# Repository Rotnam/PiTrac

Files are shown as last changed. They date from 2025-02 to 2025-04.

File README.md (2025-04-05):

**Introduction to PiTrac:**

- [Introduction](#introducing-pitrac)
  - [Project Page](#project-page)
- [PiTrac - Start Here](#getting-started)
- [PiTrac - Setup and Configuration](#setup-and-configuration)
- [PiTrac - Join the Discord](#join-the-discord)

## Introducing PiTrac
Introducing [PiTrac](https://hackaday.io/project/195042-pitrac-the-diy-golf-launch-monitor) \- the world’s first (free\!) open-source golf launch monitor (as far as we know). 



PiTrac uses low-cost Raspberry Pi(\*) computers and cameras to determine golf ball launch speed, angles and spin in three dimensions.  PiTrac interfaces with both GSPro and E6/TruGolf simulators, and its output is also accessible on a stand-alone web-based app.  \[We’ve reached out to 2k/TopGolf, but no response yet.\]

PiTrac uses off-the-shelf hardware, and includes a [parts list](https://github.com/jamespilgrim/PiTrac/blob/main/Documentation/PiTrac%20-%20DIY%20LM%20%20Parts%20List.md) with links to potential suppliers.  The only custom part is a small printed circuit board.  The fabrication instructions for that PCB are included in the open-source distribution and it can be manufactured for a few dollars.  The two Pi computers and cameras are the most expensive parts, and cost around $250 in total.

PiTrac is not a commercial product for sale–the full design is being released as open source on GitHub for folks to build themselves.  It’s not easy, but if you’re handy with a soldering iron, can figure out how to 3D print the parts, and are willing to burrow into the Linux operating system to compile and install software, you should be able to create your own PiTrac\!  

We are hoping that we can inspire a community of developers to help test and continue PiTrac’s development.  This is a really immature project right now.  The basic features usually work reliably, but the current release is a bit dodgy.  We’re looking for folks to try building their own PiTracs and help us improve the documentation and design to make it easier for other people to do the same.

## Project Page
Please visit our [project page](https://hackaday.io/project/195042-pitrac-the-diy-golf-launch-monitor) and also our YouTube channel [here](https://www.youtube.com/@PiTrac) for more details and videos.  The [GitHub repository](https://github.com/jamespilgrim/PiTrac) is in the works and already has the 3D printed part designs, the hardware design and initial software documentation.  If you’re interested in more of the details and some of PiTrac’s development history, please look through the [project logs](https://hackaday.io/project/195042-pitrac-the-diy-golf-launch-monitor#menu-logs).  

Finally, any help at our [support page](https://ko-fi.com/Pitrac) would be appreciated to continue this work and complete the release process.

(\*) Raspberry Pi is a trademark of Raspberry Pi Ltd.  The PiTrac project is not endorsed, sponsored by or associated with Raspberry Pi or Raspberry Pi products or services.

## [Getting Started](/Documentation/PiTrac%20–%20START%20HERE.md)
The process of building your own PiTrac DIY Launch Monitor is described here at a high level. There are several more-detailed instruction documents elsewhere in the PiTrac repository that are referred to below for various sub-assemblies and tasks like compiling the code and preparing the build environment.

## [Setup and Configuration](/Documentation/Raspberry%20Pi%20Setup%20and%20Configuration.md)
The instructions which are targeted toward getting setup on a step-by-step basis. These instructions start with a Raspberry Pi with nothing on it, and are meant to describe all the steps to get from that point to a working, compiled version of PiTrac.  PiTrac currently requires two Raspberry Pi’s, so the majority of these instructions will have to be repeated twice.  Because the ‘smaller’ Pi system that connects to Camera 2 is the only Pi that handles the Tomcat/Tomee web-based GUI for the system, there are a few more steps for that system.

## [Join the Discord](https://discord.gg/vGuyAAxXJH)
The PiTrac discord is where you can get help or show off your PiTrac build, discuss features and get to know other PiTrac builders. PiTrac is still a new project, so the Discord is a way to clear up any fuzzy parts of the initial ecosystem. Click the link above or copy this invite link in Discord: `https://discord.gg/9nEeVrPX`.

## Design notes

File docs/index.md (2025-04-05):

---
title: Home
layout: home
nav_order: 1
---

### PiTrac - The DIY Golf Launch Monitor

- As seen on [Hackaday](https://hackaday.io/project/195042-pitrac-the-diy-golf-launch-monitor)
- Also on [Reddit](https://www.reddit.com/r/Golfsimulator/comments/1hnwhx0/introducing_pitrac_the_open_source_launch_monitor/)

The PiTrac project is a fully-functional golf launch monitor that avoids the need for expensive high shutter-speed and high frame-rate cameras. We've developed techniques for high-speed, infrared, strobe-based image capture and processing using cameras such as the Pi Global Shutter camera (~US$50 retail) and Raspberry Pi single board computers.

PiTrac determines ball speed, launch angles, and spin in 3 axes. Its output is accessible on a stand-alone web app. Interfaces to popular golf-course simulators including GsPro and E6 are working. 2k/TopGolf never responded to our requests.

<p align="center">Introduction to PiTrac's Enclosure
&nbsp;
<iframe width="640" height="420" src="https://www.youtube.com/embed/1pX95VoKsS4?si=O_Mzlwz3F93mBZXC" frameborder="0" allowfullscreen></iframe>
</p>

----

[^1]: [It can take up to 10 minutes for changes to your site to publish after you push the changes to GitHub](https://docs.github.com/en/pages/setting-up-a-github-pages-site-with-jekyll/creating-a-github-pages-site-with-jekyll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).

[Just the Docs]: https://just-the-docs.github.io/just-the-docs/
[GitHub Pages]: https://docs.github.com/en/pages
[README]: https://github.com/just-the-docs/just-the-docs-template/blob/main/README.md
[Jekyll]: https://jekyllrb.com
[GitHub Pages / Actions workflow]: https://github.blog/changelog/2022-07-27-github-pages-custom-github-actions-workflows-beta/
[use this template]: https://github.com/just-the-docs/just-the-docs-template/generate

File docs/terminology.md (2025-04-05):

---
title: Terminology
layout: home
parent: Home
nav_order: 1.2
---

### Terminology 

<table>
  <tr>
    <th>Device</th>
    <th>Description</th>
    <th>Notes</th>
  </tr>
  <tr>
    <td>Flight Camera</td>
    <td>This is the modified camera that will be installed on the first floor of the enclosure. Bottom camera.</td>
    <td> 
    - This camera is attached to Core Pi.<br>
    - Previously known as camera 2. In scripts, may be referred as such.
    </td>
  </tr>
   <tr>
    <td>Tee Camera (As in, Tee off)</td>
    <td>This is an unmodified camera that will be installed on the top floor of the enclosure. Top camera</td>
    <td> 
    - This camera is attached to Tee Pi.<br>
    - Previously known as camera 1. In scripts, may be referred as such.
    </td>
  </tr>
     <tr>
    <td>Tee Pi </td>
    <td>This Raspberry Pi that is used for the shared directory--Samba Server. It is recommended that you use a faster Pi (e.g. Pi5) for this Pi. Installed on the top floor of the enclosure.</td>
    <td> 
    - Connected to the Tee Camera (The top floor Camera).<br>
    </td>
  </tr>
       <tr>
    <td>Flight Pi </td>
    <td>Flight Pi - used for messaging running ActiveMQ and Apache Tomee. Installed on the bottom floor of the enclosure.</td>
    <td> 
    - Connected to the Flight camera (the modified camera).<br>
    </td>
  </tr>
</table>

### PiTrac 
<a href="https://1drv.ms/i/c/35c1f51c7fbc7aba/IQSr4Eu550wjRoRfLHclEgkAARA1St3Qvlx-dvPuE9Aupqc?width=1024">
PiTrac
</a>

### Diagram
<a href="https://1drv.ms/i/c/35c1f51c7fbc7aba/IQRJJ03UsL98QbZK4ppRKmdsAQ_Gr50rl9IbFNyvEkk1Wyg?width=1030&height=894">
PiTrac Diagram
</a>

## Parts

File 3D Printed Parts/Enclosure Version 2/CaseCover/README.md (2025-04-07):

**Description:**

The Case Cover is the output protective (and aethetic) case that surrounds the inner component tower of the PiTrac version 2 enclosure.  The Case Cover consists of two parts - a Lower Half and an Upper Half.  This part separation is to allow the cover to printed on most standard-size 3D printers. The top part of the Case Cover also acts as a way of easily picking up the entire PiTrac unit.
A [FreeCAD 1.0](https://www.freecad.org/downloads.php) compatible parameterized model is included here along with .stl files.

**Printing Notes:**

PLA works well for this, but PETG probably would as well. 

Recommended print settings: 2 perimeter layers, 15% infill, grid or rectilinear infill patterns, custom painted-on supports (see the Prusa Slicer .3mf file for where the supports are needed). Both upper and lower halves require glue-stick glue on the printer bed and we recommend a 7mm brim assist because of the very small print base surface.
You'll want to paint on supports and support-exclusions so that the only places with support on the upper half of the case are the three rectangular holes that provide access to the Compute Board.

**Assembly Notes:**

See the [main assembly instructions](https://github.com/jamespilgrim/PiTrac/blob/main/Documentation/PiTrac%20Version%202%20Assembly.md).
Ultimately, the two parts will be glued together with something like thick, slower-drying super-glue such as Starbond Gap Filler Thick High Performance Super Glue.

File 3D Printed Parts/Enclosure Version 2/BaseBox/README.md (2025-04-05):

**Description:**

The Basebox is the base of the PiTrac version 2 enclosure.  The Basebox consists of three parts - a Main Body, an End-Cap that fits into the body, and a Light Shield that fits into the other two parts.  The Basebox houses the Meanwell power supply unit and secures the tower that holds all of the electronics, cameras, and other parts. 
A [FreeCAD 1.0](https://www.freecad.org/downloads.php) compatible parameterized model is included here along with .stl files.

**Printing Notes:**

PLA works well for this, but PETG probably would as well. The main body is printed standing on its closed end, which makes for a pretty high print.  You may need to make sure your printer won't have problems near the top of the print.

Recommended print settings: 2 perimeter layers (3 for a little more strength), 15% infill, grid or rectilinear infill patterns, custom painted-on supports (see the Prusa Slicer .3mf file for where the supports are needed). The main body requires glue-stick glue on the printer bed and we recommend a 7mm brim assist because of the height and relatively small print base.  
The end-cap is a pretty easy print, and should not need glue or a brim.

The Light Shield Body prints pretty well with any settings, but we use 2 perimeter layers, 15% infill, grid infill and no supports, brims, or glue.

Note that a beginning of a sketch for an x-shaped leveling support base has been started in the model, but is not finished and not yet printable.

**Assembly Notes:**

See the [main assembly instructions](https://github.com/jamespilgrim/PiTrac/blob/main/Documentation/PiTrac%20Version%202%20Assembly.md).

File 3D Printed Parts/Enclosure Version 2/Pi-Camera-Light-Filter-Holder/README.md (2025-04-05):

**Description:**

This holder secures a 1”x1” filter on the front of a standard 6mm 3MP Wide Angle Lens for Raspberry Pi Cameras. The filter slips into the pocket (held by friction), and then the holder attaches to the front of the lens via a simple friction mount. A [FreeCAD 1.0](https://www.freecad.org/downloads.php) compatible parameterized model is included here along with .stl files.

The [DIY golf launch monitor project](https://hackaday.io/project/195042-diy-golf-launch-monitor) is using this filter to restrict the light entering a Pi Global Shutter Camera sensor to just infrared (IR) light. The filter for the project is a [1" x 1", Optical Cast Plastic IR Longpass Filter](https://www.edmundoptics.com/p/1quot-x-1quot-optical-cast-plastic-ir-longpass-filter/5421/) (1.5mm nominal thickness), but the model is parameterized, so the holder can easily be modified to fit other thicknesses (or sizes) by modifying the parameter in the “Master Document” spreadsheet named “'PiFilterHolderFilterThickness”.

Consider supporting this work and the DIY LM project here: <https://ko-fi.com/PiTrac> Please and Thank You!

**Printing Notes:**

PETG works better for flexibility of the holder, but PLA also works. The holder is modeled in two pieces because we struggled with the mess added by supports in a single filter. But, if folks can improve on this, that would be great! Maybe print the whole thing at 45 degrees?

Recommended print settings: 2 perimeter layers, 20% infill, gyroid infill patterns, no supports. Does not required glue-stick or brim assists.

**Assembly Notes:**

Use just a few small drops of cyanoacrylate (super) glue to attach the outer filter holder to the part of the holder that slips over the lens. Otherwise, the glue may restrict the passage into which the filter is placed. Use the little lip around the holder to position the two pieces while gluing. Avoid gluing top portion of filter window where the little retainer bumps are. This allows the retainer to flex a bit when the filter moves past it. After setting/drying, a 1” filter should just slip in and click securely into place.

To remove the filter, if necessary, use a small screw-driver to push the filter out using the little window on the bottom of the holder.

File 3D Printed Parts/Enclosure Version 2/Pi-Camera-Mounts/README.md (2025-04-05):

**Description:**

A camera mount that accommodates the Pi GS (Global Shutter) and HQ cameras with an attached 6mm 3MP Wide Angle Lens for Raspberry Pi Cameras. The mount can tilt up/down and swivel around a bolt that attaches the base of the mount to a flat surface. A [FreeCAD 1.0](https://www.freecad.org/downloads.php) compatible parameterized model is included here along with .stl files.

The [DIY golf launch monitor project](https://hackaday.io/project/195042-diy-golf-launch-monitor) is using these mounts for two Pi Global Shutter Cameras that capture the images for the monitor. Several variations can be printed—see the annotated printed-part image. One variation is relatively low for use with a camera whose up/down tilt is minimal. Another variation is taller, allowing the camera to be tiled down by at least 30 degrees. The model is parameterized, so the mount can easily be modified to fit other needs by modifying the parameters in the “Master Document” spreadsheet, such as the “GSCam2GimbalHoleHeight” parameter. Ensure that there will be sufficient clearance between the CSI ribbon cable on the bottom of the camera and the gimbal base of the mount.

Please consider supporting this work and the DIY LM project here: <https://ko-fi.com/PiTrac>

**Printing Notes:**

PLA or PETG works well with this mount.

Recommended print settings: 4 perimeter layers (less if the bolts are not expected to be tightened very much), 15% infill, grid infill patterns, no supports. For some printers, supports to help with the curved surfaces that rotate around the horizontal axes. See .3mf file. Does not required glue-stick or brim assists.

**Parts Needed for Assembly:**

| **Quantity** | **Hardware** | **Purpose** |
| --- | --- | --- |
| 4 each | 2.5M x 16mm<br><br>2.5 Hex Nuts | Pi Camera Attachment Bolts (camera to back plate) |
| --- | --- | --- |
| 2 each | M4 x 12mm <br><br>M4 Hex Nuts | Pi Cam Gimbal Attachment Hinge |
| --- | --- | --- |
| 1 each | M5 x 12<br><br>M5 Hex Nut | Pi Cam (Pan) Swivel Mount (on bottom of mount) |
| --- | --- | --- |

**Note:** For the screws, stainless steel seems to be stronger than black carbon steel, though both can work. Especially in the stiffer PLA material, stainless is preferable because black carbon can break if torqued too much. For parts supply examples see [HanTof 525 Pcs 304 Stainless Steel M2 M3 M4 Phillips Pan Head Self Tapping Wood screws Assortment Kit](https://www.googleadservices.com/pagead/aclk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)., mxuteuk M2.5 Screw Assortment Set,M2.5 x 4/6/8/10/12/16/20/25mm Hex Socket Head Cap Screws Bolts Nuts Kit,400PCS 304 Stainless Steel Assorted Screws with Hex Wrench G035-M2.5, and [Besitu 1760pcs M2 M3 M4 M5 Metric Screw Assortment, Grade 12.9 Alloy Steel Hex Socket Head Cap Metric Bolts and Nuts Kit, Black Zinc Plated and Anti Rust Metric Screw Set with 4 pcs Hex Wrenches](https://www.amazon.com/dp/B0C38YFL3D?ref=ppx_yo2ov_dt_b_fed_asin_title)

**Assembly Notes:**

Start by placing the nuts in their positions. It’s easier to place each of the three nuts into its respective indent, and then temporarily place a strip of tape (e.g., scotch) over the nut to keep it in place while assembling the mount. Next, mount the camera to the backplate using 4 2.5M bolts and nuts. Then mount the backplate to the gimbal base using 2 M4 bolts. Finally, secure the entire mount to whatever base will hold it by using an M5 bolt.

The mount’s tilt and pan angles will generally stay put once the nuts are tightened, simply based on the friction between the parts. If the angles cannot be finely tuned, sanding the parts helps.

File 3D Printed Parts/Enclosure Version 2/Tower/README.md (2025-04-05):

**Description:**

The Tower component is the backbone of PiTrac.  Most of the components (cameras, strobe, and Compute Board PCBA) are mounted on the front of the Tower. The Tower consists of two parts - a Frontplate and a Backplate.  This part separation is to allow the Tower to printed with a minimum of supports.  The top part of the Case Cover (and particularly the Shank Shield risers that the shield scews into) can also act as a way of easily picking up the entire PiTrac unit.
The Tower does not include the Shank Shield, which is made from a piece of 3/16" or 1/4" polycarbonite (recommended for durability) or plexiglas.
The Frontplate and Backplates parts are each further split into two halves to allow printing.  The height would otherwise be too tall for most printers.  
As discussed in the Assembly Notes, these resulting four parts are glued and screwed together to make up the tower.
A [FreeCAD 1.0](https://www.freecad.org/downloads.php) compatible parameterized model is included here along with .stl files.

**Printing Notes:**

If you are slicing the parts yourself, you will need to manually split each of the Frontplate and Backplate.  See the [FIGURE- 'Frontplate Split Example - Prusa.png'] for how to do this on the Prusa Slicer.  Other Slicers have a similar ability to slice the parts.  
In order to result in a strong combined tower part with strong lap-joints, we suggest splitting the Frontplate 104mm up from the bottom and the Backplate up 145mm).  See the two Datum planes in the FreeCad 3D model called 'Suggested Frontplate Split DatumPlane' and 'Suggested Backplate Split DatumPlane' for confimation of these cut-planes.

PLA works well for this, but PETG probably would as well. 

Recommended print settings: 2 perimeter layers, 15% infill, grid or rectilinear infill patterns.  No supports or brims should be necessary.

**Assembly Notes:**

See the [main assembly instructions](https://github.com/jamespilgrim/PiTrac/blob/main/Documentation/PiTrac%20Version%202%20Assembly.md).
Ultimately, the four parts will be glued together with something like thick, slower-drying super-glue such as Starbond Gap Filler Thick High Performance Super Glue and then screwed together with 
12 M2 x 6 self-tapping screws.

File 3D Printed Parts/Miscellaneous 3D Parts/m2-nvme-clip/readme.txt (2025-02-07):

Print with 0.08mm (extra fine) or 0.12, (fine) layer height, support on build plate only - tree(auto) - style: tree slim

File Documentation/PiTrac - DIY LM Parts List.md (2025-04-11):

**PiTrac \- DIY LM  Parts Lists**

**Computing Hardware:**

| Quantity | Hardware | Purpose |
| :---- | :---- | :---- |
| 1 | [Raspberry Pi 5](https://www.raspberrypi.com/products/raspberry-pi-5/) and power supply, 4 GB minimum, 8 FB recommended. | Getting a bundled kit with the Pi and power supply and some other things can be economical if you don’t have any Pi-related stuff yet. |
| 1 | [Raspberry Pi 4 Model B](https://www.raspberrypi.com/products/raspberry-pi-4-model-b/) and power supply, 4 GB minimum.  It may also make sense for a little more money just to get a second Pi 5\. |  |
| 1 | [Pimoroni NVMe Base for Raspberry Pi 5 \- PIM699](https://www.adafruit.com/product/5845) ((optional, but recommended for speed and longevity). [This board](https://www.amazon.com/gp/product/B0CQ4D2C9S/ref=ppx_yo_dt_b_search_asin_title?ie=UTF8&psc=1) works well, too. | For the Pi 5, this allows use of an NVMe memory drive instead of an MicroSD card. |
| 1 | An [NVMe solid state (SSD) memory drive](https://www.amazon.com/gp/product/B0BGFRZDTB/ref=ppx_yo_dt_b_search_asin_title?ie=UTF8&psc=1) (optional, but recommended for speed and longevity) | Typically with an M.2 M key edge connector, in the 2230 and 2242 form factors.  Should probably get at least 256 GB capacity. |
| 2 | Micro SD cards (to bootstrap the Pi’s). | We recommend 64GB size |
| 1 | An Active Cooler fan for the Pi 5 (optional) | The Pi 5 can get pretty hot if you’re doing a lot of big compiles on it.  If so, having a cooler seems like decent insurance. |

**Hardware \- Bolts and Nuts:[^1]**

| Quantity | Hardware | Purpose |
| :---- | :---- | :---- |
| 4 | M4 x 12 screws | LED Power supply hold-downs |
|  |  |  |
| 4 | 2.5M x 12mm bolt | Pi 1 Board Bolt-down |
| 4 | 2.5 Hex Nuts | Pi 1 Board Bolt-down |
| 3 | 2.5M x 10mm bolt | Pi 2 Board Bolt-down |
| 1 | 2.5M x 12mm bolt (odd one\!) | Pi 2 Board Bolt-down |
|  |  |  |
| 2 x 4 | 2.5M x 16mm 2.5 Hex Nuts | Pi Camera Attachment Bolts (to back plate) |
| 3 x 2 3 x 2 | M4 x 12mm  M4 Hex Nuts  | Pi Cam Gimbal Attachment Hinge (2 cameras and strobe gimbal) |
| 2 x 1 2 x 1 | M5 x 12 M5 Hex Nut | Pi Cam (Pan) Swivel Mount (on bottom of mount) |
|  |  |  |
| 3 x 2 | M3 | Horizontal Center-Side Body Attachment |
| 4 | 2.5 x 10 or 12 | Connector Board Bolt-down |
| 3 x 6 \= 18 | M3 x 10mm | Floor hold-down screws |
|  |  |  |
| 2 x 4 | 2.5M x 12mm bolt | Connector Board Mounting Bolts |
| 2 x 4 | 2.5 Hex Nuts | Connector Board Mounting Bolts |
| 8 | M3 x 10mm | LED and LED Lens Hold-down screws |
|  |  |  |
| 2 2 | M3 x 12mm M3 Nuts | Half-Join bolts and nuts for ceiling level walls |
| 2 2 | M3 x 16mm M3 Nuts | Half-Join bolts and nuts for base and middle level walls |
| 5 x 4 | M3 x 10mm self-tapping screws | These screws secure the five “floor” components to their respective “wall” components and/or other floor components |

**Camera and Lighting Hardware:**

| 2  | [Raspberry Pi Global Shutter Camera – CS Lens Mount](https://www.adafruit.com/product/5702) | The cameras currently used by the LM.  They do not come with lenses (see below) |
| :---- | :---- | :---- |
| 1 | [Raspberry Pi 5 FPC Camera Cable \- 22-pin 0.5mm to 15-pin 1mm \- 300mm long](https://www.adafruit.com/product/5819) | The current Pi Cameras have a CSI cable that needs a conversion to fit into the smaller CSI ports on the Pi 5\.  The 200mm should probably work as well. |
|  | [200 mm Flex Cable for Pi 4](https://www.adafruit.com/product/2087) | This likely comes with most Pi Cameras, so may not be necessary |
| 2 | [6mm 3MP Wide Angle Lens for Raspberry Pi HQ Camera \- 3MP](https://www.adafruit.com/product/4563) | Wide angle lens for the Pi GS cameras (which come without a lens) |
| 1 | [1" x 1", Optical Cast Plastic IR Longpass Filter](https://www.edmundoptics.com/p/1quot-x-1quot-optical-cast-plastic-ir-longpass-filter/5421/) (1.5mm nominal thickness) | Blocks visible light below 850nm from entering the Camera 2 sensor |
|  |  |  |
| 1 | [60 / 120 Degree LED Lens Optical Glass 44mm \+ Reflector Collimator \+ Fixed Bracket for 20W 30W 50W 100W COB High Power Chip (60Degree 100W len kit)](https://www.amazon.com/dp/B09XK7QTV5?ref=ppx_yo2ov_dt_b_fed_asin_title)  | The lens helps focus the infrared IR light. |
| 1 | [High Power LED Chip IR 730nm (you want the 850nm) 850nm 940nm 3W 5W 10W 20W 30W 50W 100W COB Integrated Matrix Light Beads for Night Vision Camera (Select the 850NM, 100W 1Pieces)](https://www.amazon.com/dp/B09DPJYRQN?ref=ppx_yo2ov_dt_b_product_details&th=1)  | The 730nm IR Led used for strobe light.  NOTE \- this device can get very hot if left constantly on for even a few seconds.  PiTrac just uses it in short pulses. |
| 1 | [Aclorol USB COB LED Strip Lights for TV 5V USB Powered LED Tape Lights Daylight White 6.56FT 320Leds/M 6000K COB Flexible Light Strip TV Led Backlight for Bedroom Under Cabinet Kitchen DIY](https://www.amazon.com/Aclorol-Powered-Daylight-Flexible-Backlight/dp/B0D1FYV3LM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) | LED strip for lighting the teed-up ball- long enough to double it for more light. 
NOTE - The Strip should produce NO infrared light, or else it will interfere with the IR strobing that the system uses.
|

**Power-Related Parts:**

| 1  | LED Driver, 12-26V, Output Current DC 3600mA, such as: https://www.aliexpress.us/item/2251832563139779.html NOTE - Also need a power-plug for some of these drivers that just come with power wires.  For the US, see, e.g., [this](https://www.amazon.com/sspa/click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)| Driver for LED strobe array. Because of the short pulses that are used in the LM, a much smaller (and cheaper) driver may also work, possibly even a non-constant-current driver. |
| :---- | :---- | :---- |
| 1 | A 5V USB-B power supply with a male micro USB connector  | This is currently necessary to run the Connectro Board.  The supply is used as an isolated, independent (downstream of a transformer) power plane to try to keep the Pi’s and the Pi Camera safe. |
|  |  |  |

**Connector Board Parts:**

| Item | Qty | Reference(s) | Value | LibPart | Footprint / Details |  |
| :---- | :---- | :---- | :---- | :---- | :---- | ----- |
| 1 | 1 | J3 | \~ | [USB B Micro Female Pinboard](https://www.amazon.com/Pinboard-MELIFE-Interface-Adapter-Breakout/dp/B07W6T97HZ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) | The included Pin headers can be used for the parts below |  |
| 2 | 2 | R1, R4 | 330 ohm R | Resistor A decent assortment kit is [here](https://www.amazon.com/gp/product/B003UC4FSS/ref=ppx_yo_dt_b_search_asin_title?ie=UTF8&psc=1) | Resistor\_THT:R\_Axial\_DIN0207\_L6.3mm\_D2.5mm\_P10.16mm\_Horizontal |  |
| 3 | 2 | R2, R3 | 270 ohm R | Resistor | Resistor\_THT:R\_Axial\_DIN0207\_L6.3mm\_D2.5mm\_P10.16mm\_Horizontal |  |
| 5 | 1 | Sys1\_Conn1 | \~ | 4 Pin Header | Connector\_PinHeader\_2.54mm:PinHeader\_1x04\_P2.54mm\_Vertical |  |
| 6 | 1 | Sys2\_Conn1 | \~ | 3 Pin Header | Connector\_PinHeader\_2.54mm:PinHeader\_1x03\_P2.54mm\_Vertical |  |
| 7 | 2 | U2, U3 | H11L1 | [Isolator:H11L1](https://www.amazon.com/dp/B09KM2BJCF?ref_=pe_386300_442618370_TE_sc_as_ri_0) | Package\_DIP:DIP-6\_W7.62mm |  |
| 8 | 1 | U4 | 74HC04 | 74xx:74HC04 | Package\_DIP:DIP-14\_W7.62mm\_Socket |  |
| 9 | 1 | U5 | \~ | [Dual\_Mos\_Driver\_Module](https://www.amazon.com/Anmbest-High-Power-Adjustment-Electronic-Brightness/dp/B07NWD8W26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) | Verdant\_Custom\_Footprint\_Library:PCB Dual MOS Driver Module |  |
|  | 1 | 2.5M Bolt 2.5M Nut |  |  | These help mechanically tie down the USB-B power connector to the board |  |
|  |  | \<Optional\> |  |  |  |  |
|  | 2 | 6 \- pin DIP socket |  | A decent assortment kit is [here](https://www.amazon.com/dp/B01GOLSUAU?ref=ppx_yo2ov_dt_b_fed_asin_title) | The opto-isolators and the hex inverter chip are probably the most likely to be blown up or injured by solder over-temps.  So best to put them in sockets |  |
|  | 1 | 14 \- pin DIP socket |  | A decent assortment kit is [here](https://www.amazon.com/dp/B01GOLSUAU?ref=ppx_yo2ov_dt_b_fed_asin_title) |  |  |

**Miscellaneous Parts/Supplies:**

| Quantity | Hardware | Purpose / Notes |
| :---- | :---- | :---- |
| 2 |  [Ideal Industries 30-102 Power Plug](https://www.amazon.com/Ideal-Industries-30-102-Power-72427/dp/B01LYF1WV9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). | Enables easy connect/disconnects |
| N/A | 3 and 4-pin ribbon cables For example, [here](https://www.amazon.com/Kidisoii-Dupont-Connector-Pre-Crimped-5P-10CM/dp/B0CCV1HVM9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). | These are used for the wiring harness connects between the various GPIO pins and the Connector Board |
| 1 | 15.5cm x 24cm plexiglass anti-ball-strike protective window | Protects the cameras and strobe **NOTE:**  Ensure the plexi is not IR-blocking\!  Most hardware stores can cut plexi in this size for a few US$ |
| 1 | Power Strip | A relatively short power strip that is compact enough to fit into the enclosure. 10” or less, and with some type of power filtering to protect the rest of the components |

[^1]:  Stainless Steel seems to be stronger than black carbon steel, though both can work.  Especially in the stiffer PLA material, stainless is preferable because black carbon can break if torqued too much..  For parts supply example see [HanTof 525 Pcs 304 Stainless Steel M2 M3 M4 Phillips Pan Head Self Tapping Wood screws Assortment Kit](https://www.googleadservices.com/pagead/aclk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).,

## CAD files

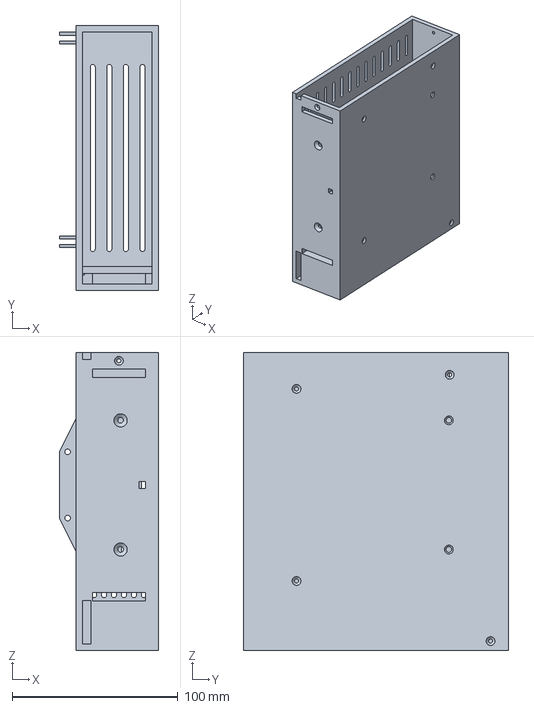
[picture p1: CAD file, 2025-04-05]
3D Printed Parts/Enclosure Version 2/BaseBox/BaseBox- Main Body.3mf
60.0 x 160.0 x 180.0 mm

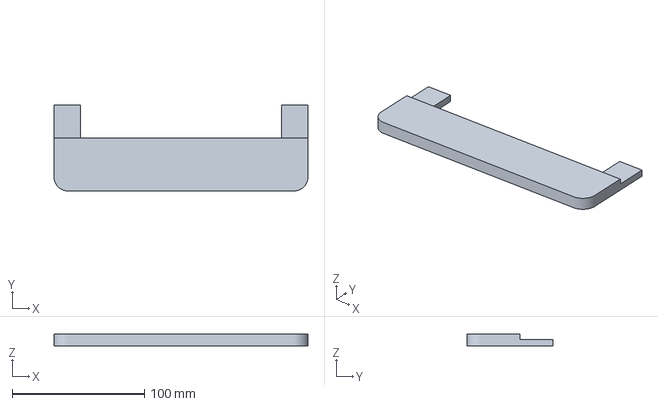
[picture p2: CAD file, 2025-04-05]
3D Printed Parts/Enclosure Version 2/BaseBox/BaseBox- Light Shield Body.3mf
192.0 x 65.0 x 9.00 mm

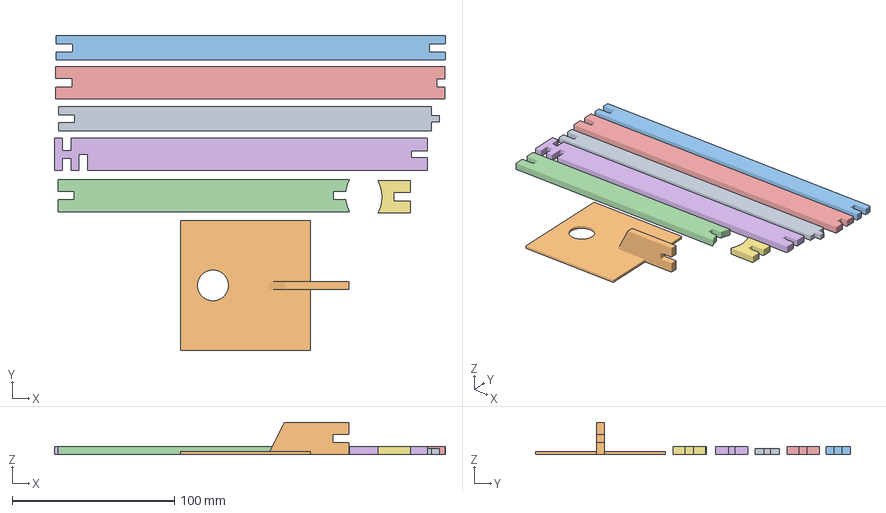
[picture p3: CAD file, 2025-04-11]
3D Printed Parts/Enclosure Version 2/Calibration Rig/Calibration Rig.3mf
241.1 x 194.0 x 20.0 mm
Calibration Rig.stl_1
Calibration Rig.stl_2
Calibration Rig.stl_3
Calibration Rig.stl_4
Calibration Rig.stl_5
Calibration Rig.stl_6
Calibration Rig.stl_8

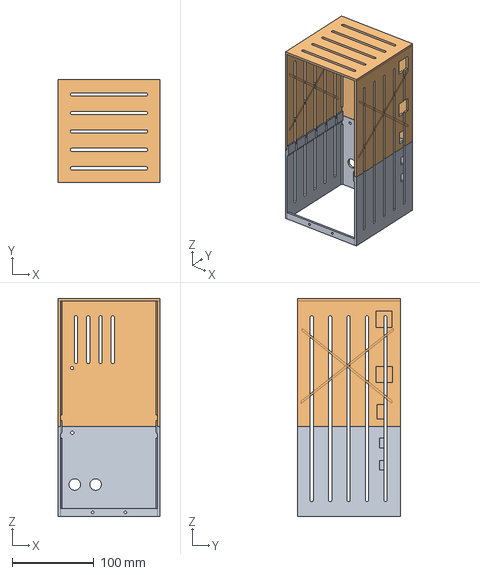
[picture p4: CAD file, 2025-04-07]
3D Printed Parts/Enclosure Version 2/CaseCover/CaseCover.FCStd
124.6 x 126.0 x 266.1 mm
Lower Case Cover Body
Upper Case Cover Body

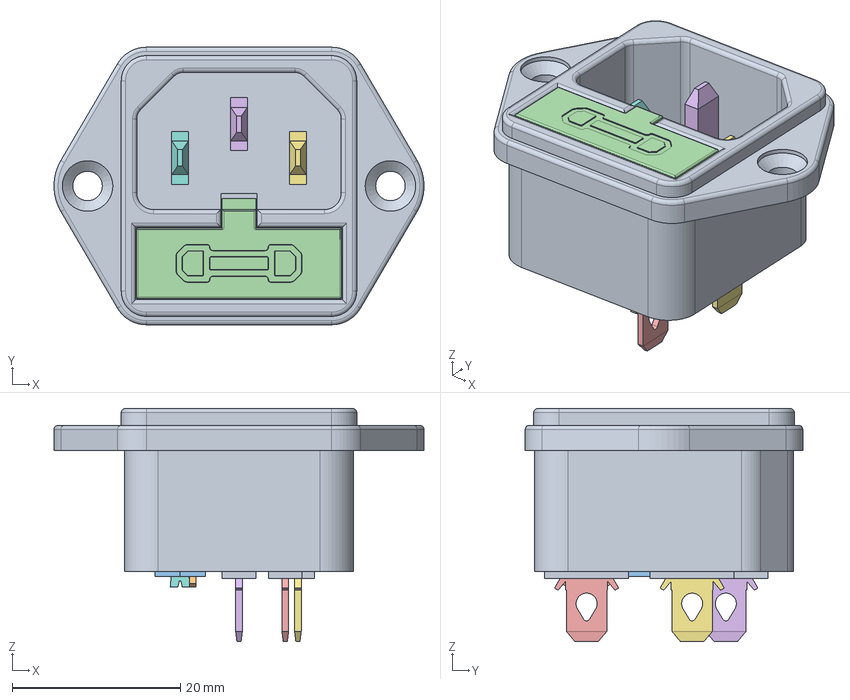
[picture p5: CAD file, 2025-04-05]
3D Printed Parts/Enclosure Version 2/Integrated Enclosure (DO NOT PRINT)/C14 Panel Mount Power Plug Adapter w Fuse - JR-101-1F.FCStd
44.0 x 33.0 x 27.7 mm
JR-101-1F
JR-101-1F001
JR-101-1F002
JR-101-1F003
JR-101-1F004
JR-101-1F005
JR-101-1F006
JR-101-1F007

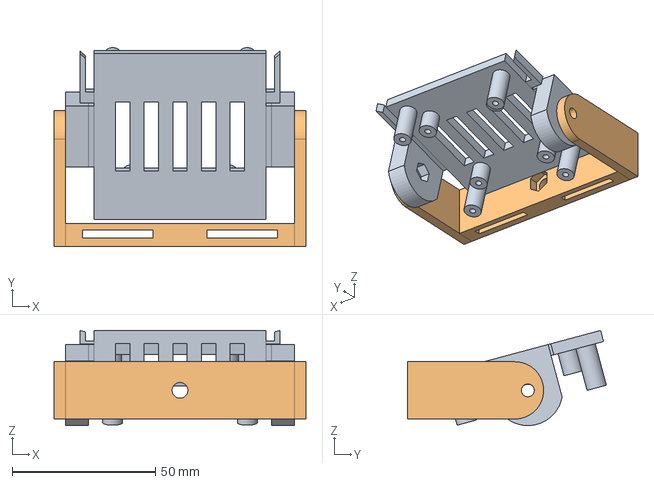
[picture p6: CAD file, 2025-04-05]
3D Printed Parts/Enclosure Version 2/LED-Array-Strobe-Light-Mount/LED Light Mount.FCStd
88.0 x 69.4 x 33.2 mm
LED Back Plate
LED Gimbal

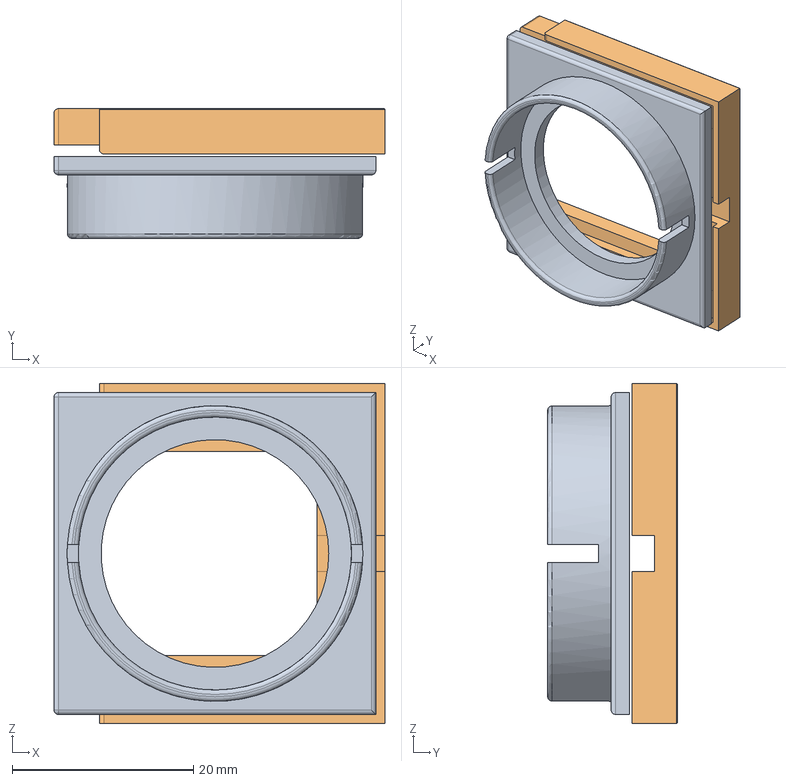
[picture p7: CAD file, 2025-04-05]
3D Printed Parts/Enclosure Version 2/Pi-Camera-Light-Filter-Holder/Pi Cam Filter Holder.FCStd
36.5 x 14.3 x 37.5 mm
Filter Holder Body
Holder Wings Body

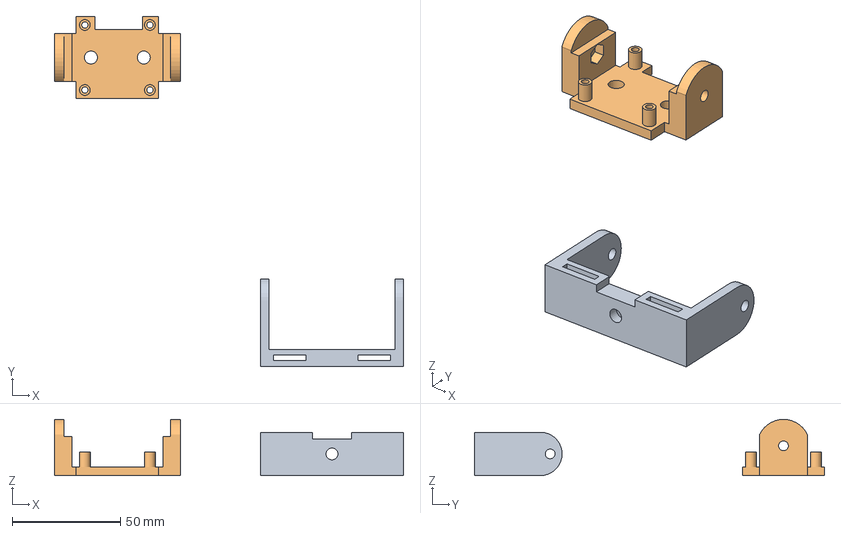
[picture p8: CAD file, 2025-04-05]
3D Printed Parts/Enclosure Version 2/Pi-Camera-Mounts/Camera Mount - Bottom Variation.3mf
161.0 x 161.6 x 25.9 mm
Camera Mount - Bottom Variation.stl_1
Camera Mount - Bottom Variation.stl_2

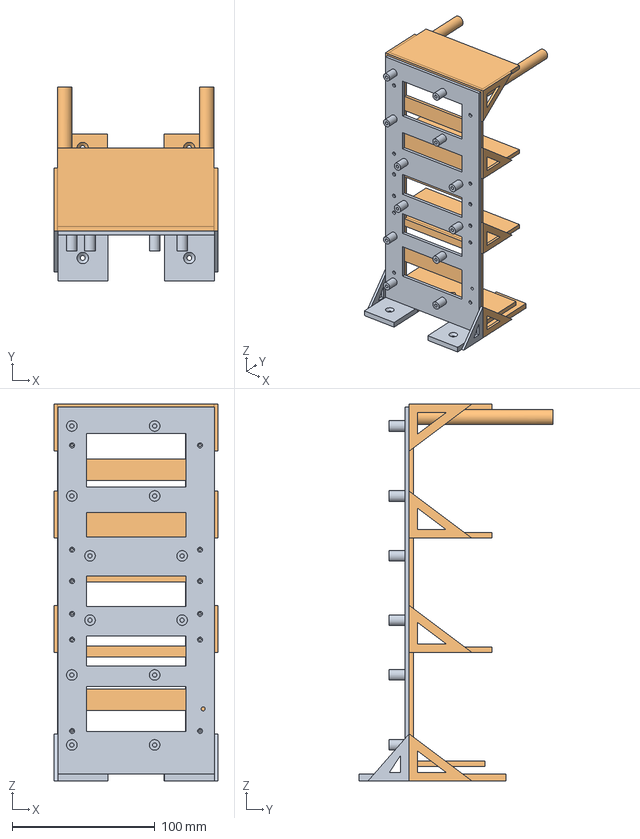
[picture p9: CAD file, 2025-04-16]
3D Printed Parts/Enclosure Version 2/Tower-Connector-Board-Variant/Tower.FCStd
114.7 x 135.7 x 264.0 mm
Backplate Body - Connector Board Variant
Frontplate Body (same as other variant)

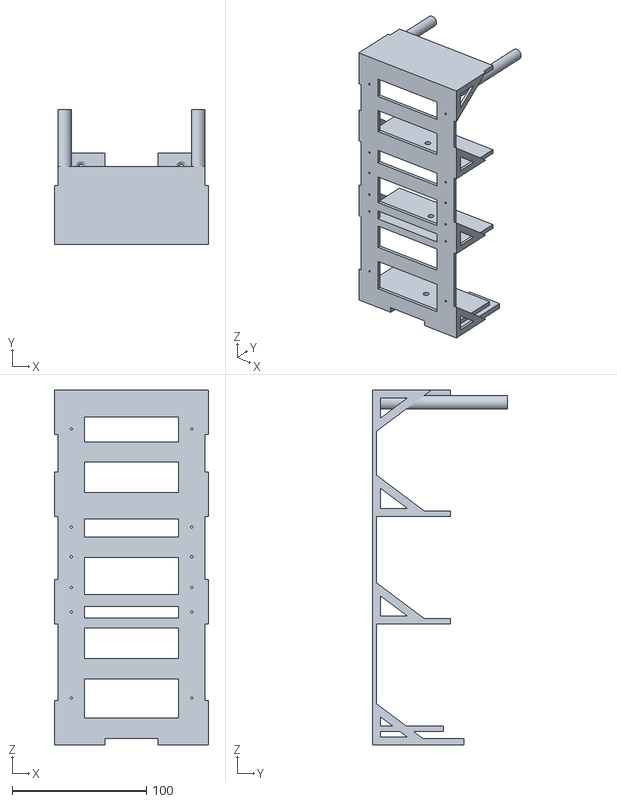
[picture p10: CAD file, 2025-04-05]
3D Printed Parts/Enclosure Version 2/Tower/Tower Frontplate Body.stl
114.6 x 100.7 x 264.0

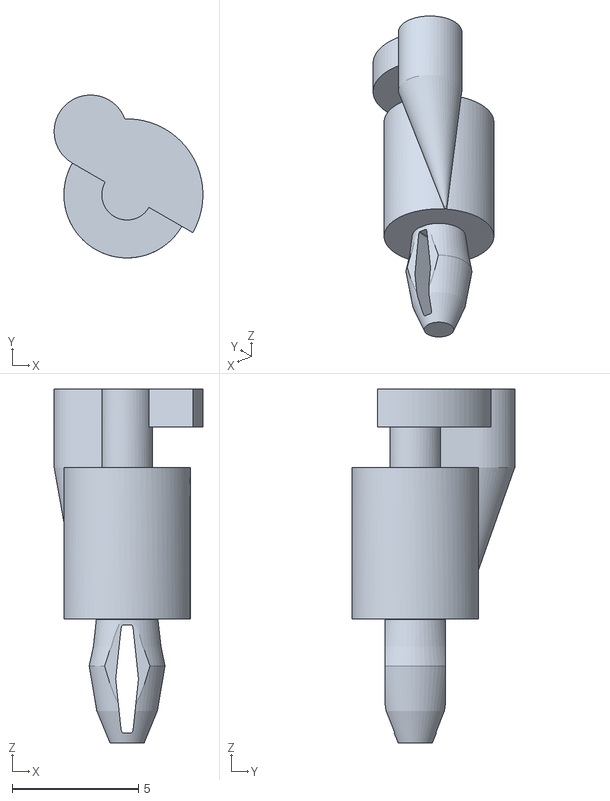
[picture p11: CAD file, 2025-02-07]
3D Printed Parts/Miscellaneous 3D Parts/m2-nvme-clip/m2nvme-clip-v1.stl
5.89 x 6.44 x 14.0

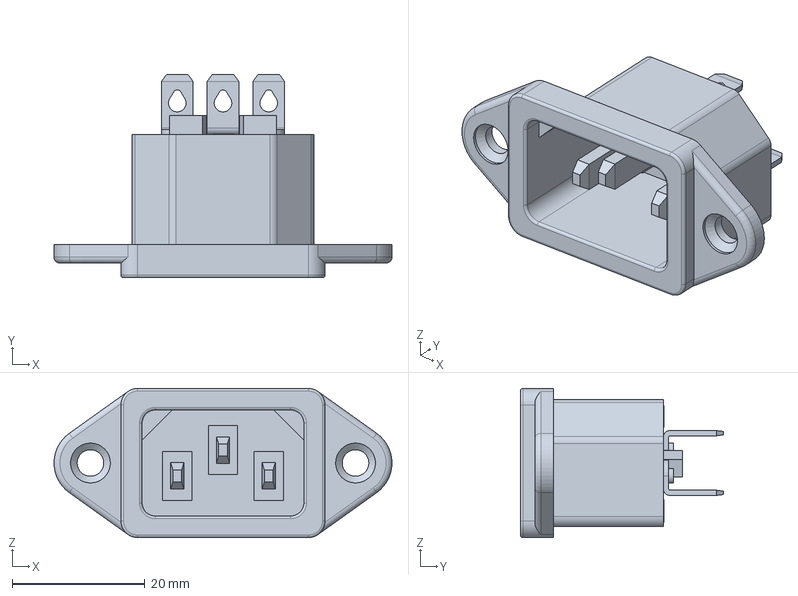
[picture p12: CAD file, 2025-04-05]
3D Printed Parts/Enclosure Version 2/BaseBox/C14 Panel Mount Power Plug Adapter.FCStd
51.0 x 30.7 x 22.5 mm

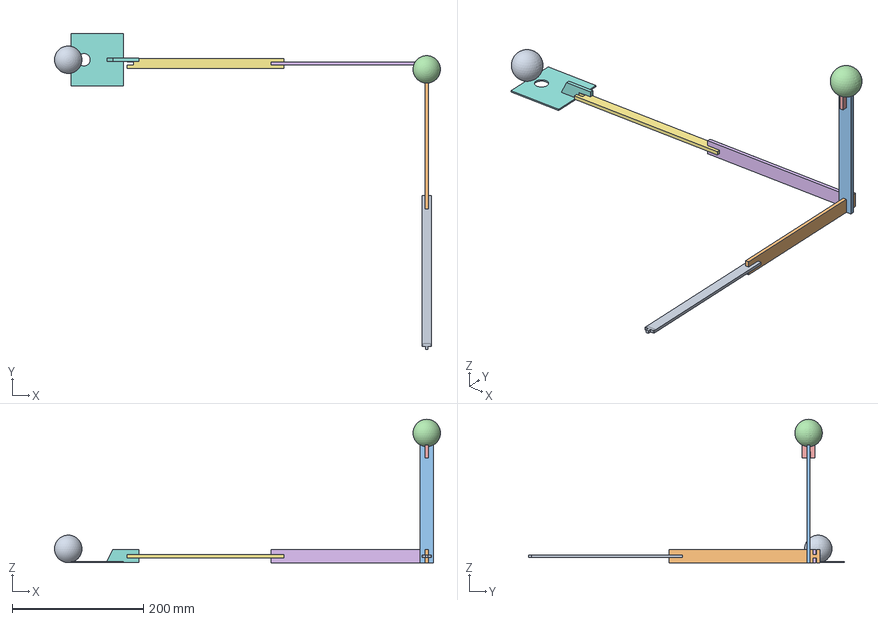
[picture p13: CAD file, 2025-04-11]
3D Printed Parts/Enclosure Version 2/Calibration Rig/CalibrationRigFCStd.FCStd
588.7 x 481.9 x 218.9 mm
Base Connection Leg Body
Z-Axis Leg Body
High Ball Holder Body
Test Golf Ball 1
High Ball Holder Cross Body
X Axis Near Leg
X Axis Far Leg
X-Axis Ball Holder Body
Test Golf Ball 2

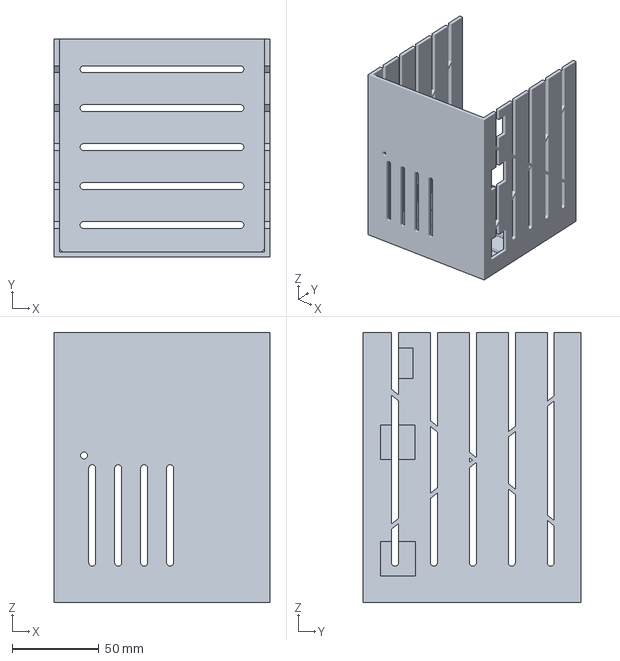
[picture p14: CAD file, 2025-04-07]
3D Printed Parts/Enclosure Version 2/CaseCover/UpperCase Cover Body.3mf
124.6 x 126.0 x 156.0 mm

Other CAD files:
3D Printed Parts/Enclosure Version 2/Master Document.FCStd
3D Printed Parts/Enclosure Version 2/Integrated Enclosure (DO NOT PRINT)/Integrated PiTrac.FCStd
3D Printed Parts/Enclosure Version 2/Pi-Camera-Light-Filter-Holder/Pi Cam Filter Holder v1.00.FCStd
3D Printed Parts/Enclosure Version 2/Pi-Camera-Mounts/Camera Mount - Bottom.FCStd
3D Printed Parts/Enclosure Version 2/BaseBox/BaseBox- Light Shield Body.stl
3D Printed Parts/Enclosure Version 2/BaseBox/BaseBox- Main Body - OLD.3mf
3D Printed Parts/Enclosure Version 2/BaseBox/BaseBox- Main Body - OLD.stl
3D Printed Parts/Enclosure Version 2/BaseBox/BaseBox- Main Body.stl
3D Printed Parts/Enclosure Version 2/BaseBox/BaseBox-BaseBox PartLight Shield Body.stl
3D Printed Parts/Enclosure Version 2/BaseBox/BaseBox-End Cap.3mf
3D Printed Parts/Enclosure Version 2/BaseBox/BaseBox-End Cap.stl
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

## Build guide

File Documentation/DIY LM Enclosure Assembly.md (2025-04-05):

**The PiTrac Assembly Guide**

Overview:  
This document explains the process of building a typical PiTrac DIY Launch Monitor (LM).  This process includes the assembly of all of the physical components, including the 3D-printed parts and hardware, such as cameras and Raspberry Pi computers.  Detailed printing instructions for the 3D parts are contained in the directories that have the respective part files.  Instructions for certain stand-alone sub-assemblies such as the camera mounts are contained in separate documents, but linked to from this main document.  Instructions for the software components of the LM are separate and available [here](https://github.com/jamespilgrim/PiTrac/blob/main/Documentation/Raspberry%20Pi%20Setup%20and%20Configuration.md).

This document also refers to the calibration steps for the camera sub-system, which should be consulted prior to building the enclosure.  This calibration is most easily done *as the LM is being assembled*, because doing so allows for easier access to the cameras and camera mounts before the LM is completed.  The calibration process can be found [here](https://github.com/jamespilgrim/PiTrac/blob/main/Documentation/PiTrac%20-%20Camera%20Calibration.zip).

At least currently, the LM is not a simple, complete kit that just requires attaching Part A to Part B.  Instead, it’s a general design for an LM that we hope the builder will customize, adapt and improve depending on their own goals and skills.  The particular parts referenced here may not even be available when someone builds the LM. For that reason, this document is less of a plan and more of a guide for building what is expected to be a ‘typical’ PiTrac LM.  The authors hope that the individual creativity, and ingenuity of the builders will help improve PiTrac and help it continue to evolve.

Conventions:  
Any references to left/right/back/front in this document are by default referring to the LM as it faces the user, with the camera side toward the builder.  “Pi-side” refers to the right half where the Pi’s, cameras, and the Connector Board are placed.  “Power side” refers to the left side where the power adapters and cables are contained.

The 3D parts are named using a house analogy.  The curved parts that make up the outside of the LM are referred to as walls.  The flat horizontal parts that will be mounted within those walls are called floors.  Some additional terminology is shown below:  


Tools Needed:

1. M2.5, M3, M4, and M5 hex wrenches.  Right-angle wrenches as well as straight (screw-driver-type) wrenches are helpful.  
2. Needle-nose pliers.  
3. Medium-sized Phillips screwdriver, at least a 6” length  
4. Soldering tools  
5. Wiring tools such as wire strippers, clippers, and anything necessary to build custom wiring harnesses  
   1. If custom-making the harnesses ribbon cable, a pin connector kit, crimping tool, etc.  
6. Optional:  
   1. A magnifying, lighted headband and/or a magnifying desk light  
   2. A Dremel tool can come in handy for trimming parts if needed.  
   3. A soft/hard rubber hammer or mallet.  Because sometimes things need a little gentle persuasion.

Parts  and Materials:

1. See the [parts list document](https://github.com/jamespilgrim/PiTrac/blob/main/Documentation/PiTrac%20-%20DIY%20LM%20%20Parts%20List.md) for a full list of parts, including all of the bolts and screws  
2. The 3D-printed parts that make up the enclosure (of course).  
3. Solder, flux, flux-cleaner  
4. Wires.    
   1. We use stereo-speaker wire for higher-voltage portions of the system and whenever keeping the two \+/i wires together for most of the wire-run is helpful.  
5. Optional:  
   1. Sand paper, sanding block  
   2. To use as a contrasting backdrop, a half-dozen (or so) square feet of non-IR-reflective cloth material, such as most black felts  
      1. You’ll have to experiment with what types of cloth show up as black when lit with IR light.  Some cloth that appears black to the eye actually looks white in IR light, which makes a poor-contrasting backdrop with a white-colored ball.

Assembly Instructions:

1. Printing the Enclosure Components  
   1. First, see the individual printing and assembly instructions for each of the 3D parts that make up the LM, [here](https://github.com/jamespilgrim/PiTrac/tree/main/3D%20Printed%20Parts/Enclosure%20Models). The 3D printing is a multi-day project in itself due to the size of some of the parts.  
   2. If possible, having the hardware components that you expect to use in hand ***before*** printing the parts will allow you to customize the part models as necessary to fit those parts.  For example, if your LED power supply is different from the one used by the authors, you’ll want to customize the mounting risers and holes on the Pi-Side Base layer to accommodate it.  
2. Base Layer (the part of the LM that touches the ground\!\!)  
   1. Overview  
      1. Several parts such as the LED power supply will be placed in the lowest section of each of two Base Layer wall parts first.  Then, the two base wall parts are connected together in the middle.  The camera assembly and Pi 2 are then attached to the Pi-side Floor.  Finally, the Pi-side and power-side floors are screwed into the mounting risers on the inside of the walls.  
   2. Wall Halves and Lower Component Bays (the areas just above the floor)  
      1. Before putting anything in the base bays, place two M3 nuts into the indents on the Pi-side half-join pads while there is still room to do so.  If tight, the nuts can be pulled into the indents by using a temporary bolt from the outside.  A little temporary scotch tape really helps hold the nuts in.  
      2. It’s easier to install the LED supply before the two bottom wall halves are joined.  The part is typically heavy, so best to keep it low in the enclosure.   
      3. Place the LED power supply in the right-hand half and secure to the risers on the floor with four M4 x 12 screws.  The design is set up to accommodate [this supply](https://www.aliexpress.us/item/2251832563139779.html), though others should work.  Different supplies will require different distances between the LED supply riser mounts, of course.    
      4. The output wires of the supply should have a quick-connect to make it easier to connect to the Connector Board later.  Make sure the polarity of the two wires is clearly marked.  Putting polarity markings on the quick-connect helps.  The input should have a 3-prong plug that can be plugged into a utility strip on the power-side of the LM.    
      5. If your network switch will fit and still allow for cable connections, place it in the Power-side bay now.  One cable will be routed out the back of the LM, and two cables will lead from the switch over to the Pi’s on the right side of the LM.  
         1. It may be easier to lay down two Cat-5/6 cables through the Pi-Side bay now rather than after the floor is attached.  They may be threaded between the LED power supply and the base floor later (see completed Base Layer, below)  
      6. Join the two base halves using two pairs of M3 x 16mm bolts and nuts.  
   3. External (Tee-up) LED lighting  
      1. Install LED lighting under the overhang near the bottom of the Base Layer.  This lighting helps the high-FPS camera 1 see the ball more clearly despite the short shutter speeds.  This can be done after mounting the floors, but it’s more difficult.  However, the pictures below show the LED strips being installed after the floor.  Because we messed up.  
      2. If you’re using [the same LED strips we are](https://www.amazon.com/Aclorol-Powered-Daylight-Flexible-Backlight/dp/B0D1FYV3LM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), it’s best to make it brighter by using two levels of stripping.  To do this, start by tacking down one end of the strip on the left-side of the Base Layer under the overhang.  Position it so the end goes inside the LED light port by a few inches     
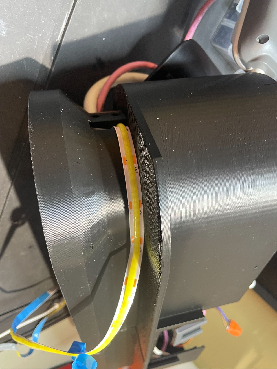
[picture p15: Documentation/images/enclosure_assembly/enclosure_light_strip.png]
      3.   
      4. Then, remove the sticky backing and stick one layer down just below the overhang, making a small, loose bend that is pushed about 4 inches into the right-hand LED port.  Stick down the next layer of the strip just below the first layer so that there are two rows of LED lights under the overhang.  
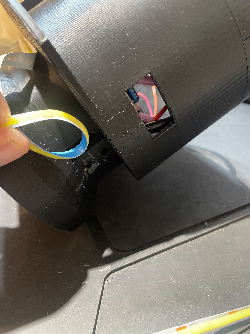
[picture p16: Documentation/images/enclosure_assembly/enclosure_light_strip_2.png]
      5.  
      6. Pull the end of the LED strip that has the USB (or whatever) power plug through the left-most LED port.  This end will either plug into the power strip within the PiTrac, or (usually better), will be pulled back out the back port that has the main power cable and the network cable.  Doing so allows the power to stay on to the Pis and the rest of the monitor, but the LED strip can be turned off when the ball is not actively being hit.  It’s quite bright and can get warm, so it’s nice to be able to turn it off.  
      7. Use the two small holes at the ends of the Base Layers to thread zip-ties through.  Use the zip-ties to (lightly) secure the ends of strips.  If your LED strip is super-sticky, you may not need the zip-ties.  
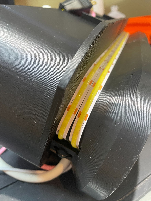
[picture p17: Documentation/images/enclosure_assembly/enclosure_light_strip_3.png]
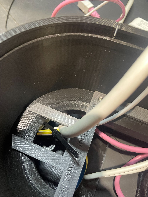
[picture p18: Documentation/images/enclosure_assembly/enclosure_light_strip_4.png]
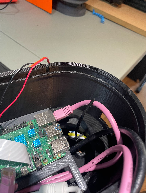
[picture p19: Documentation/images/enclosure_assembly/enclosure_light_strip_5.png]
      8.   
   4. Camera 2 (the camera on the bottom that takes pictures of the ball in flight)  
      1. Camera modifications  
         1. First, one [GS camera](https://www.raspberrypi.com/products/raspberry-pi-global-shutter-camera/) has to be modified to (1) use IR light instead of visible light, and (2) to allow for external triggering of its shutter .    
            1. **WARNING** \- these modifications will void the warranty on the camera.  They are also pretty delicate, and can wreck the camera if performed incorrectly  
         2. Remove the internal IR filter that would otherwise keep any IR light from entering the sensor.  Use [official instructions here](https://www.raspberrypi.com/documentation/accessories/camera.html#filter-removal).  
         3. Modify the Global GS Camera to accept external triggering.  Use the [instructions from RPi](https://github.com/raspberrypi/documentation/blob/develop/documentation/asciidoc/accessories/camera/external_trigger.adoc) as a guideline. The removal of the resistor is a particularly difficult step, and you’ll want to use a good magnifying work light and some steady hands\!  
         4. Because you’ll likely be connecting and disconnecting the camera several times, use wires with jumper pin ends (or other quick-connect devices) to make the process easier.    
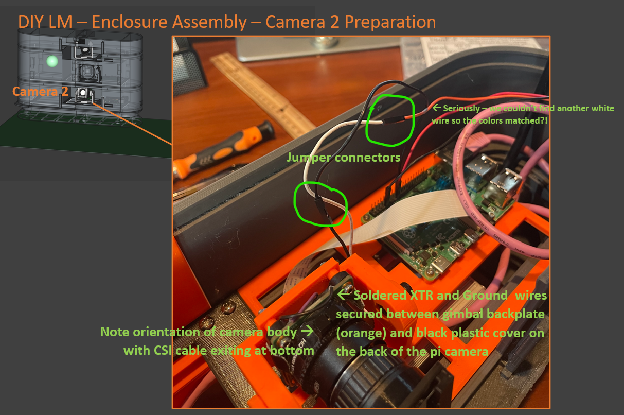
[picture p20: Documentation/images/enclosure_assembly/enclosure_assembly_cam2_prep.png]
         5.  
         6. This is the most delicate part of the entire DIY LM assembly process, so work slowly.  Removing the extra resistor is especially difficult, so consider practicing first on an old surface-mount PCB that you don’t use any more. (doesn’t everyone have those?:)  
         7. Once the XTR and GND wires are soldered to the board, add a small drop of thick glue over the wire and solder to help act as a strain relief.  Also for strain relief, we ran the wires down from the top of the camera (see picture above) and gently pinched the wires between the camera and the backplate of the camera gimbal assembly.  Doing so protects the wires a bit by having them come out near the bottom of the gimbal away from other things they might snag on.  
      2. Assemble the Pi GS Camera and its gimbal camera mount for the bottom camera 2  
         1. NOTE:  The bottom camera mount is shorter than the top camera mount because the bottom camera (camera 2\) does not need to point downward  
         2. Use the instructions in the Camera Mount sub-project’s README.md file [here](https://github.com/jamespilgrim/PiTrac/tree/main/3D%20Printed%20Parts/Enclosure%20Models/Pi-Camera-Mounts).  
      3. Mounting the camera to the gimbal  
         1. It is easier to attach the camera CSI cable ***before*** bolting the camera to the camera assembly’s backplate.  Make sure the cable-lock is locked on the camera so that the ribbon cable doesn’t fall out..  
         2. Carefully thread the CSI ribbon cable out the back of the camera mount making sure it does not get pinched between the backplate and the gimbal mounting base.  
      4. Add visible-light cut filter  
         1. Assemble the filter holder by gluing the two parts of the filter together using the registration wings to position the two parts together.:  
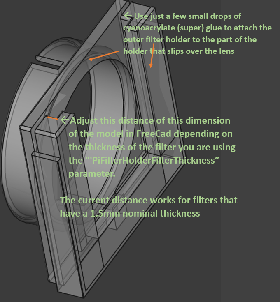
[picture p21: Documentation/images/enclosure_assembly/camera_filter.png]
         2.  
         3. See instructions [here](https://github.com/jamespilgrim/PiTrac/tree/main/3D%20Printed%20Parts/Enclosure%20Models/Pi-Camera-Light-Filter-Holder).   
         4. Insert the visible light-cut filter and attach the holder to the lens with the opening at the top so the filter doesn’t drop out  
   5. Pi-side Base Layer Floor  
      1. NOTE:  The two floors holding the RPis are similar.  Double check the labeling on the part to ensure the correct floor is used in each step  
      2. Mount Camera 2 on Floor 1 using an M5 bolt and nut.  It’s best to have the CSI cable and GND and XTR (external trigger) wires all in place and secure before mounting.  
      3. Mount the Pi 4 (a 5 works, too) on the right side of Floor 1 using 4 M2.5 x 12 bolts and nuts, with the nuts on the bottom side.  Put the Micro-SD card (if used) in place beforehand when it’s more accessible.    
      4. Connect the camera’s flat CSI cable to the Pi.  
      5. Connect the camera’s GND to pin 9 of the Pi.  
      6. Create the Pi 2-to-Connector-Board ribbon cable and plug it in  
         1. To do so, fashion a three-wire ribbon cable harness with female plugs on each end.  If possible, have a black and a red wire, with the third wire for the Camera 2 XTR.  See the lower half of this photo for finished wiring:  
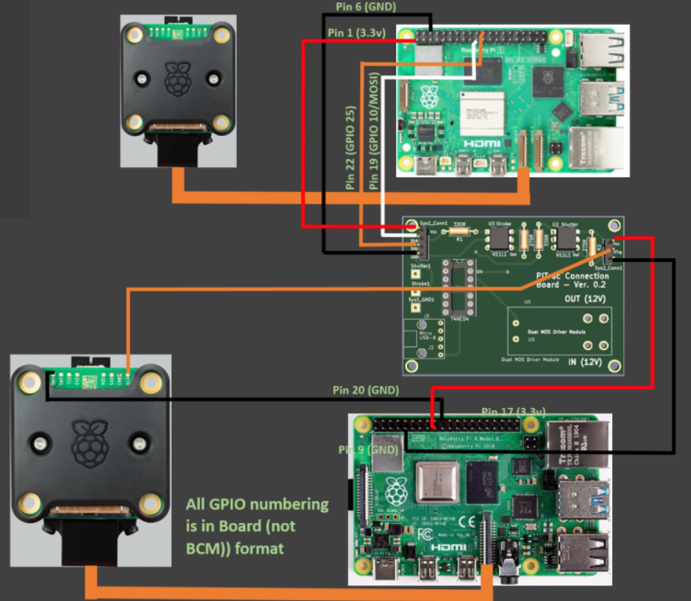
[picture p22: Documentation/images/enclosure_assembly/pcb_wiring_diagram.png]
         2. 
         3. NOTE \- Low-quality wiring harnesses in this part of the build can lead to random, difficult-to-diagnose problems later.  Make sure that the wiring harnesses will connect firmly and without any play to the pins on the Connector Board.  Making the cables a little longer than necessary also makes life easier.  
         4. Pre-crimped ribbon cable parts are by far easier to use than having to solder your own.  See [here](https://www.amazon.com/Kidisoii-Dupont-Connector-Pre-Crimped-5P-10CM/dp/B0CCV1HVM9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) for an example assortment kit.  
         5. An example (with more intermediate connectors than necessary) is:  
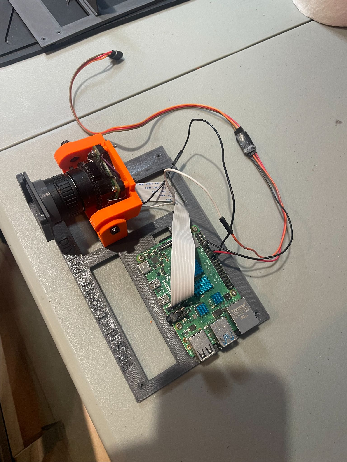
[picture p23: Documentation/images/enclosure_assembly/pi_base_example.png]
         6.  
   6. Joining the two Base Layer Floor halves  
      1. The two base-floor halves join in an overlapping lap joint in the middle.  The lap joint helps secure the two halves of the LM together.  
      2. Ensure that any printing supports on the power-side floor lap joint are removed and that the joint is smooth and will mate well with the pi-side floor.  A careful belt-sanding may help.  
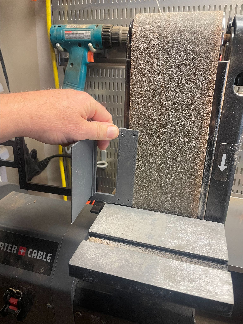
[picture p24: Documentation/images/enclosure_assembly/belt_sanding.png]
      3. 
      4. Start by screwing 6 M3 x 10mm screws a few turns into the 4 holes on the power-side floor and the right-most (outside) 2 holes on the Pi-side floor.  It’s easier than placing them later  
      5. Slip the lap joint of the Power-side floor between the camera base and the lap joint of the Pi-side floor so that the right-most screws of the power-side are aligned with the left-most two holes on the Pi-side.  It will likely be a little tight.  Screw just the two screws in the overlapping holes so that the two sides are held (barely) together.  This process is easier than trying to join the two floors after they are both placed inside the base walls.  
      6. Set the tenuously-joined Pi-side Floor 1 and Pi-side Floor into the joined Base-Layer walls, with the Pi on the right..  The lap-joint (and two screw holes) should be aligned in the middle.   
      7. Screw the floors into the mounting pads on the side of the walls using M3 x 10mm screws.  Note that the two screws on the lap joint go through both floors and into the side pads of the Pi-side wall.  
      8. Make sure any cables you will need later such as network cables are not trapped or pinched.  Also make sure the LED Power Supply power cable is accessible on the left side.  
      9. The joined base layer assembly will look like:  
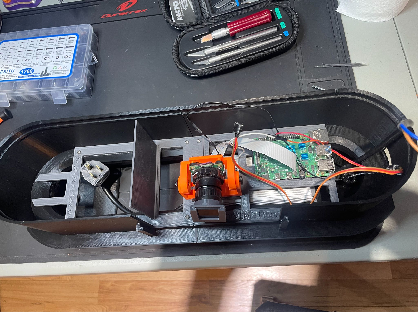
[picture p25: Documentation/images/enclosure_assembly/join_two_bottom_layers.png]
      10. 
   7. Completing the Base Layer  
      1. Run the power cable from whatever power-strip will be used down through the left-most power-strip support and down and out the hole on the power-side base.  This is usually a tight fit, so do it first.  
      2. Route a power cable from the Pi power supply to the Pi 2 computer board.  It may be a little tight with the network cables.  
      3. Route one of the network cables to the Pi.  
      4. The completed Base (lowest) Layer should look similar to:  
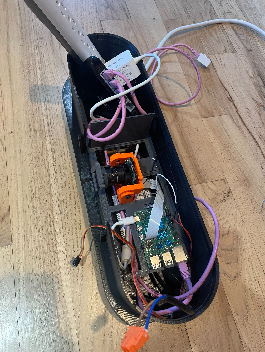
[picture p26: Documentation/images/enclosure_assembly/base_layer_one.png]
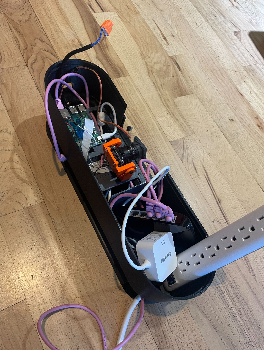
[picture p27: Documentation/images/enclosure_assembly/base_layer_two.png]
      5.  
      6.   
      7. Preparation for Middle Layer  
         1. In preparation for mounting the Middle Layer on the Base Layer, gently move the cables that will connect from the Base Layer to components in the Middle (and above) layers:  These cables include:  
            1. Network cable from the network switch (will connect to the Pi 1 on the upper floor of the Middle Layer)  
            2. 3-wire wiring harness from the Pi 2 on the base layer (will connect to the Connector Board on the lower floor of the Middle Layer  
            3. LED strobe power cable from the LED power supply in the Base Layer (will connect to the LED strobe on the lower floor of the Middle Layer  
         2. Each of these cables typically are routed off to the right.  
   8. Camera 2 Calibration  
      1. Now is the time to calibrate Camera 2\.  The camera is easily accessible at this point, and it will be more difficult to deal with once the Middle Layer of the LM is in place above it.  
      2. See Calibration Document [here](https://github.com/jamespilgrim/PiTrac/blob/main/Documentation/PiTrac%20-%20Camera%20Calibration.zip).  
3. Middle Layer assembly, including Second (middle) and Third (top) floors  
   1. Overview  
      1. Like the Base Layer, the Middle Layer consists of two wall halves that join together in the middle.  However, there are two floors on the right (Pi) side in the Middle Layer.  The lower Pi-side floor holds the strobe LED and the Connector Board.  The upper floor holds the Pi 1 computer and Camera 1\.  The wall halves are joined first.  Then, the components are attached to the Pi-Side lower floor half, and then the Pi-side and Power-Side Lower Floors are secured to the lower part of the Middle Layer.  Inter-floor wiring is completed, then the Pi-side Upper Floor is put in place in its respective half above the Lower Floor.  
   2. Build the Strobe Assembly  
      1. See Strobe Mount instructions [here](https://github.com/jamespilgrim/PiTrac/tree/main/3D%20Printed%20Parts/Enclosure%20Models/LED-Array-Strobe-Light-Mount).  
   3. Build the Connector Board  
      1. See Connector Board instructions (separate project) [here](https://github.com/jamespilgrim/PiTrac/tree/main/Hardware/Connector%20Board).  
      2. Ensure the two 12V IN and OUT wiring pairs and the 4-wire harness is attached to the Connector Board’s screw terminals before mounting the Floor to the Wall half  
         1. Attaching the wiring harnesses to the Connector Board on the ***lower*** floor early is essential because it is difficult to access the board once the ***top*** layer Pi-side floor is installed.  
         2. The 3-wire harness should already have been attached to the Pi 2 and the Pi Camera 2 in the Bottom Layer  
   4. Joining the Middle Layer Wall Halves  
      1. Place four M3 nuts into the indents on the Pi-side half-join pads.  If the fit is tight, the nuts can be pulled into the indents by using a temporary bolt from the outside.  Tape can help hold the nuts in their indents.  
      2. Join the two base halves using four pairs of M3 x 16mm bolts and nuts.  
      3. If necessary, disconnect the two sides and sand the half-join areas to ensure the two halves come together tightly without unsightly gaps.  
   5. Build the Middle Layer Lower Floor (Strobe & Connector Board) Assembly  
      1. Mount the Connector Board to the Lower Floor so that the 4-pin connection header is on the left and the writing is upright.  Mount the Board with four self-tapping M3 x 8mm or 10mm screws.    
      2. Mount the strobe assembly (LED and gimbal) using an M5 bolt that comes up from below the floor through an M5 nut in the indent in the base below the LED strobe light.  Position the LED power wires so that they lead back through the side wire holders on the Strobe Assembly.  Face the strobe straight out from the LM and tighten the M5 bolt now while it is easily accessible.  
   6. Mount the Lower Pi-side and power-side Middle Layer floors to the bottom of the lower mounting pads on the side of the Middle Layer walls.  
      1. Both of the lower floors mount on four screw holes on the ***underside*** of the lower floor mount pads using four self-tapping M3 x 10mm screws.  Do not over-tighten.  Note that the floor is below the pads, but the components are on the upper side of the floor.    
      2. The Middle Layer (without the 3- and 4- wire wiring harnesses or power) with the two lower floors looks like:  
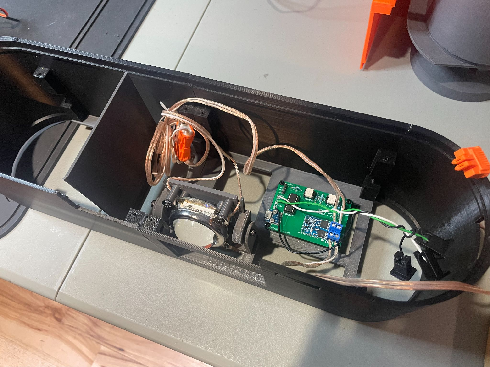
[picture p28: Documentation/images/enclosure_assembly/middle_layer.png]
      3.   
      4. Now is the time to route a 5V micro-USB power cord to the Connector Board and attach it.  Whatever 5V adapter is left on the left side bay.  
   7. Assemble the Camera 1 camera assembly  
      1. This assembly is similar to the Camera 2 assembly, but Camera 1 will be pointing downward fairly steeply, so the Camera 1 assembly has the camera mounted a little higher on a taller riser than the other camera.  Make sure you use the correct camera assembly so that the camera can point at a downward angle.  See the Camera Mount Assembly instructions, [here](https://github.com/jamespilgrim/PiTrac/tree/main/3D%20Printed%20Parts/Enclosure%20Models/Pi-Camera-Mounts): See photo below::   
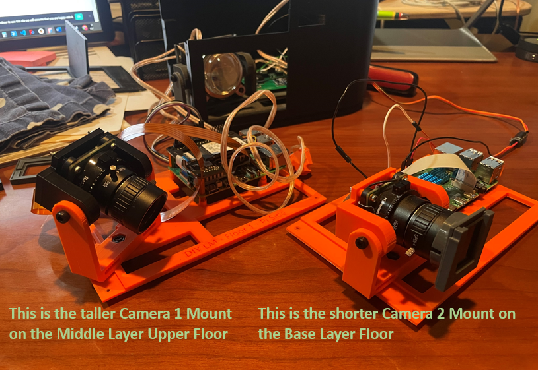
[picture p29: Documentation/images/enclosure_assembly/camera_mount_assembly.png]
      2.  
      3. Camera 1 uses visible light, so no external filter or modifications are necessary.  
   8. Assemble the Pi-side Middle Layer Upper Floor  
      1. **NOTE**\- this step follows the directions for the ***Base*** Layer Pi-side floor pretty closely, since both of these floors have a Pi and a Pi camera..  The two floors holding the RPis are similar.  Double check the labeling on the part to ensure the correct floor is used in each step  
      2. Mount the Camera 1 Assembly on the Middle Layer Upper Floor using an M5 bolt and nut.  It’s best to have the CSI cable in place and secure before mounting.     
         1. **NOTE:** Camera 1 uses a different adapter cable than Camera 2\.  
         2. See photo, above.  
      3. Mount the Pi 5 on the right side of Floor 1 using 4 M2.5 x 12 bolts and nuts, with the nuts on the bottom side.  Put the Micro-SD card (if used) in place beforehand when it’s more accessible.    
         1. Because we expect this Pi 5 to be used as a development platform in addition to being an operational part of the PiTrac, using an NVmE memory instead of an SD card is recommended.  An active cooler is also a good idea for those long compiles.  
      4. Connect the camera’s flat CSI cable to the Pi 5\.  Note that a special cable is necessary here because the Pi 5 uses a smaller size-format connector.  
   9. Mounting the Pi-side Middle Layer Upper Floor to the Middle Layer Wall  
      1. After confirming that both wiring harnesses are connected to the Connector Board, guide the 4-wire harness and the second network cable  to the right of the upper floor as you place the upper floor on the four mounting pads of the Pi-Side Middle Wall.  This will enable those wire wires to be connected to the Pi 1 on the Middle Layer upper floor.  
      2. Mount the upper floor to the side pads using four M3x10mm self-tapping screws.  
      3. Connect the 4-wire ribbon cable from the left side of the Connector Board in the lower floor to the GPIO pins of the Pi 1 computer on the upper floor.  See the upper part of the wiring diagram here:  
         1.  
      4. Connect the second network cable to the Pi from the switch in the base layer  
      5. Connect a Pi-5 compatible power supply (we used [this one](https://www.amazon.com/CanaKit-PiSwitch-Raspberry-Power-Switch/dp/B07H125ZRL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)) from the Power-Side to the Pi 5\.  Try to keep the cable out of the way of the strobe and other hardware on the lower layer beneath.  
      6. The Pi 5 should be operational at this point and the camera ready to be calibrated.  
   10. Middle-Layer Power-Side Assembly on the Middle Wall  
       1. There is no upper floor for the Middle-Layer power side.  The lower floor’s separator wall is high enough to partition off the entire power-side of the Middle Layer.  
   11. Mount the Middle Layer on the Base Layer (it’s really coming together now\!)  
       1. Before connecting the MIddle and Base Layers, make sure you have the wires from the Base Layer (especially the 3-wire harness) that will connect to the Connector Board in the Middle Layer.  
       2. Grip the Middle Layer securely by its back wall and hold it above the Base Layer with one hand so you can move things around with your other hand..  
       3. Push the network, LED power output, and Connector Board wiring harness off to the right of the Base Layer and thread them through the space on the right side of the Middle Layer as the Middle Layer is placed into position on the Base Layer.  These cables need to be connected to the components of the upper floor of the Middle Layer.  
          1. On the left-hand side: Guide whatever utility strip and power adapters you are using up through the void on the left side of the Middle Layer.  
          2. On the right-hand side: Thread the cables coming up from the Lower Layer through the space on the far-right of the Middle Layer, just to the right of the lower floor.  See below for what this should look like as we start to put the two layers together:  
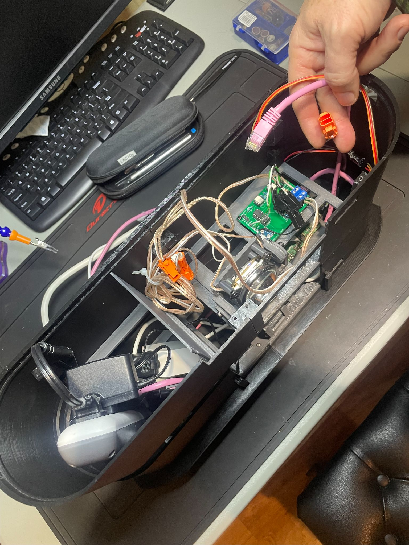
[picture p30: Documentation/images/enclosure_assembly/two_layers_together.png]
       4.  
       5. ***BEFORE*** trying to fully connect (snap together) the two layers, make sure that all of the various wires are well inside the walls and will not be pinched or cut between the layers when they come together\!  
       6. Gently insert the inner-wall click-tabs at the bottom of the Middle Layer into the inside of the wall tabs at the top of the Base Layer.  It’s often easier to set the upper layer into the back of the lower layer and then pull outward on the front of the Base Layer to help the top layer tabs click into the Base Layer.  
       7. Resist the temptation to hit the top–most layer down into the base layer.  And NOTE \- the top of the MIddle Layer is fairly sharp\!  
   12. Connect the output of the LED power supply in the Base Layer to the wires screwed into the Dual MOS switch of the Connector Board – marked as “IN (12V)”  
       1. **WARNING** \- Check and then double-check that the polarity of the wires is correct.  Using wires that have clear markings (such as a white-strip on one wire of a wire pair) helps.  If the LED is connected backward, it could be destroyed.  
       2. Using ‘keyed’ wire connector blocks that can only be connected in one way  (and not flipped) is a sound practice.  
       3. Most of the MOS switches that can be used with the Connector Board will have polarity markings on the MOS switch board.  For example, see below:  
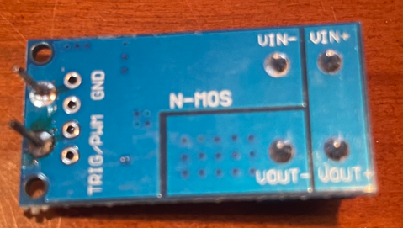
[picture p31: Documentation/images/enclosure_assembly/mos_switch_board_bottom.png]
       4. 
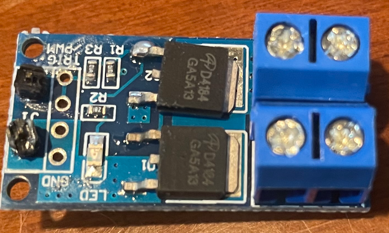
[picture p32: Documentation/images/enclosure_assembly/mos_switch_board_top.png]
       5.  
       6. Note however, that the components you source may be different\!  
   13. Connect the wire leads from the “OUT (12V)” terminals of the Connector Board to the  LED Strobe.  
       1. Make sure you don’t accidentally connect the strobe directly to the ***output*** of the LED power supply.  Doing so could melt the strobe assembly or worse.  
       2. Same warning on polarity as above.  
   14. Connect the wiring harness from both the Pi 2 (the Pi on the Base Layer floor) and the Pi Camera 2 from the Base Layer below up to the Connector Board   
       1. Using the schematic layout in the next subsection, below), ensure that the correct wires from the Camera 2 and the Pi 2 in the Base Layer are connected to the correct header pins on the Connector Board  
4. Securing the Base and Middle Layers  
   1. Secure the layers using M3 x 6mm self-tapping screws in the four screw holes at the interfaces of the bottom of the Middle Layer and the top of the Base layer.  Dulling the tips of the inter-floor screws (which currently overhang into the layer interiors) for safety is a good idea.  
5. Camera 1 Calibration  
   1. Prior to putting the ceiling over the upper camera 1, calibrate that camera using the separate Camera Calibration document [here](https://github.com/jamespilgrim/PiTrac/blob/main/Documentation/PiTrac%20-%20Camera%20Calibration.zip)  
6. Top Wall (Ceiling) section assembly  
   1. Connect the two ceiling halves using four M3 bolts and screws.  
   2. Snap the ceiling section onto the top of the Middle Layer.  Secure with 4  M3 x 6mm self-tapping screws in the four screw holes at the interfaces of the bottom of the Ceiling Layer and the top of the Middle Layer.  Dulling the tips of the inter-floor screws (which currently overhang into the layer interiors) for safety is a good idea.  
7. Add the Front Window  
   1. Add the protective 15.5cm x 24cm  plexiglass anti-ball-strike window by sliding it down into the mounting slots in the ceiling and base-layers.  The plexi window should be far enough away from the cameras and strobe light so that a ball strike against the window should not hit those expensive components.  
8. PiTrac Badge/Logo  
   1. The PiTrac badge is built from separately printing the back plate of the badge, and the letters (and parts of the “PiTrac” letters) and then putting them together.  
   2. You can pick the colors you’d like to use, of course.  We use the following palette:  
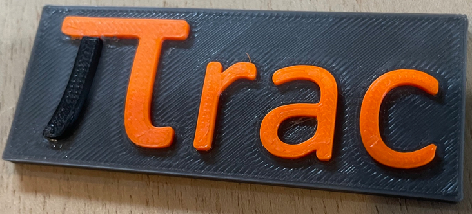
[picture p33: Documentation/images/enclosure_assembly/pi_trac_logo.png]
   3.  
   4. The parts fit better if they are printed full-sized for the back plate, and at 99% size for the characters.  After printing out the parts shown above, a hard-rubber hammer makes it easy to tap the characters into place.  Friction is enough to hold the parts together, but a little cyanoacrylate glue wicked into the joints will secure them permanently.  
   5. We attach the badge using 2-sided tape, as the rough surfaces don’t glue together very well.  
9. Next step is to go through the Start Up documentation [here](https://github.com/jamespilgrim/PiTrac/blob/main/Documentation/PiTrac%20Start-Up%20Documentation.md).

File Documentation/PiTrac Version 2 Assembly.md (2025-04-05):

**The PiTrac Assembly Guide - Version 2**

Overview:  
This document explains the process of building a typical PiTrac DIY Launch Monitor (LM) using the Version 2 Enclosure and the new PiTrac Compute Board.  This process includes the assembly of all of the physical components, including the 3D-printed parts and hardware, such as cameras and Raspberry Pi computers.  Detailed printing instructions for the 3D parts are contained in the directories that have the respective part files.  Instructions for certain stand-alone sub-assemblies such as the camera mounts are contained in separate documents, but linked to from this main document.  Instructions for the software components of the LM are separate and available [here](https://github.com/jamespilgrim/PiTrac/blob/main/Documentation/Raspberry%20Pi%20Setup%20and%20Configuration.md).

TBD - This is just a placeholder document for now - Please ignore.

New Material for Enclosure 2:
Tower Construction
Screw the M2x6 self-tapping screws into the back plate just far enough so that a little of the tip of the screw goes beyond the other side.
WARNING - These little screws are delicate (especially if carbon steel), so don't over-tighten
The screws will act to help register the back plate and front plate halves of the parts of the tower.
Use thick, slower-drying super-glue such as Starbond Gap Filler Thick High Performance Super Glue to glue the halves together
The tower halves do not always have material in the same places, so take care not to add glue to portions of one half that will not be adjacent to the other half.
NOTE - make sure that the bottoms of the halves (especially for the base parts) are well-registered so that the completed, glued tower will sit and attach flat to the base box.
<PICTURES>
Use clamps judiciously to make sure the parts are glued securely
Tight the screws through the two sides as you work your way up the tower

Shank Shield Installation
2 x Pan head M4*12 or *16 self-tapping screws for the top of the shield (avoid counter-sinking, but could also use flat-head)
2 x flat head self-tapping M4*12 or *14 screws for the bottom of the shield
Put the shield in place and mark where the upper-left hold should be that goes into the top-left riser of the tower frontplate
Drill a hole in the shield using a 5/32" drill bit or something else that is very nearly as wide as the screw threads
WARNING - it's very easy to shatter or chip the shield when screwing in the screws.  For that reason, the holes must be nearly as large (or even larger) than the screws.  This may compromise the rigidity of the lower-shield mount, but better than a cracked shield.
WARNING - Plexiglas or polycarbonite is very sharp.  Make sure you sand everything.
Mount the shield using just the top-left screw.  Using a 1/8" (or other small bit), drill through the sheild in the top-right where tthe shield will mount into the top-right tower riser.  
Drill (straigh) through the two counter-sunk shield-securing holes in the front of the base-box.  The reasons for using the smaller bit is sot that there is enough plastic in the basebox hole to tightly grip the screw.
Unattach the shield, put it on something you can drill into, and drill out the three new holes with a 5/32" drill.
Attach the shield using the four screws listed above.

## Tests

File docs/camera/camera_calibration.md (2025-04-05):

---
title: Calibration
layout: home
parent: Cameras
nav_order: 2
---

## Camera Calibration

(the below pictures feature PiTrac in its early incarnation using 2x4s for its enclosure)
<table>
  <tr>
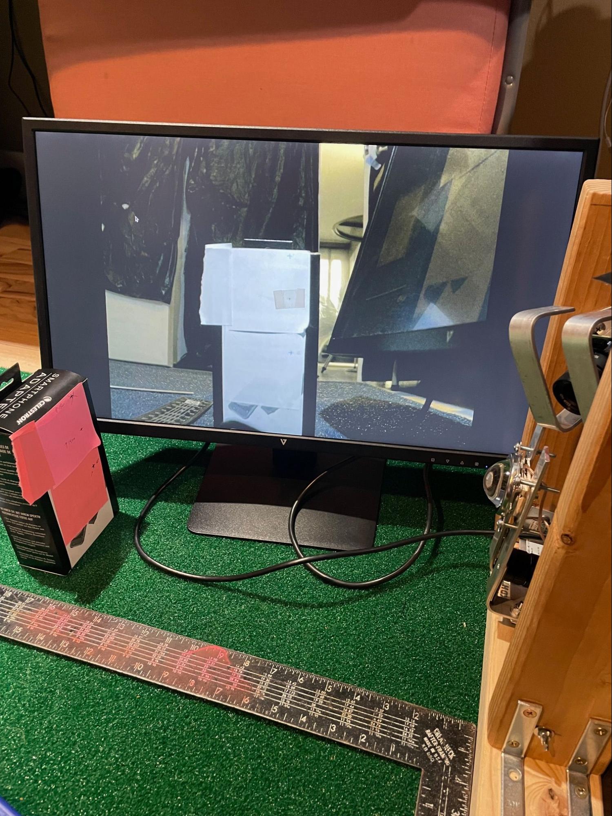
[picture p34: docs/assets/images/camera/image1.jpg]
    <th></th>
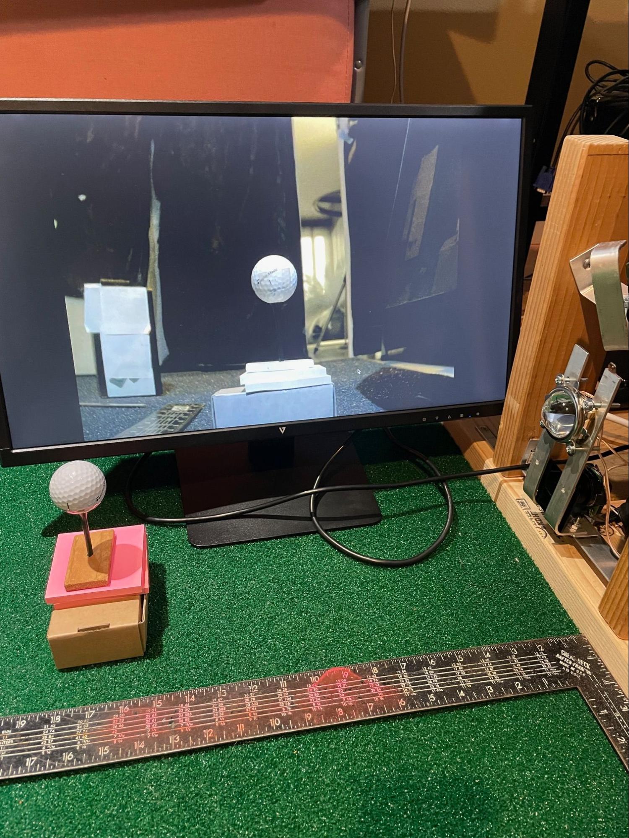
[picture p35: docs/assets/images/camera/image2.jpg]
    <th></th>
  </tr>
  </table>

### Overview

1. The PiTrac system needs to know the angles of the cameras and the relative distances between them in order to locate the ball in space. Camera calibration helps establish these values.

2. During this calibration, various distances are measured from each camera to a test point in front of the camera. Those values are used, along with this spreadsheet (which computes additional, derived values) to determine a set of calibration values. Those values are then given to the PiTrac monitor by entering them in the golf_sim_config.json configuration file, which PiTrac reads when it starts up.

3. The basic idea is to center a known point in 3D space in the camera lens and then measure the distances to that point. That in turn determines the camera’s angles. This process also establishes the effective focal distance of the camera, which in turn is used to establish the distance of the ball from the cameras.

4. After the marker points are used to aim the cameras, an actual golf-ball is used to calibrate focus and focal length.

5. It’s best to calibrate the cameras in the environment in which you expect to use the LM.

6. As part of the calibration process, the fish-eye-like distortions that are caused by most lenses need to be accounted for. These distortions are particularly evident around the edges of an image. Multiple images of a hand-held checker-board pattern are used to determine a couple of matrices that are used by the PiTrac to essentially “undistort” the images taken by the cameras.

7. The distances in this guide are in meters unless otherwise specified.

8. Note that “calibration” as used in this document is a broader process than just the intrinsic/extrinsic calibration that sets up matrices to perform de-distortion on cameras (although undistortion is a part of it).

----

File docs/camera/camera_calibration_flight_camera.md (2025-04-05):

---
title: Flight Camera (bottom)
layout: home
parent: Calibration
nav_order: 2.1
---

## Flight Camera

1. Note Flight Camera (bottom camera) closely follows the Tee Camera (Top Camera) calibration  
2. Lens Un-Distortion  
3. Measuring Distances and Angles  
    1. Remove the visible-light cut (long pass) filter from the front of the camera for now. It’s easier to calibrate the camera in the visible light spectrum.  
    2. Ensure that the triggering for the camera is not in external mode (where it usually will be when the Flight camera system is running).    
        - If necessary, do: `sudo /CameraTools/setCameraTriggerInternal.sh`   
    3. Set up a marker point (such as a cross hairs) on a piece of paper attached to an object or stand so that the point is about 15 cm above the ground and roughly centered in the view of the camera with the camera at a slight upward tilt and facing straight out.  The point should be a shape that will be crisp, sharp, and useful for focusing the camera.  
    4. Follow the instructions for Tee Camera (read that first), below, but use the following modifications when recording the various measurements:  
    5. 
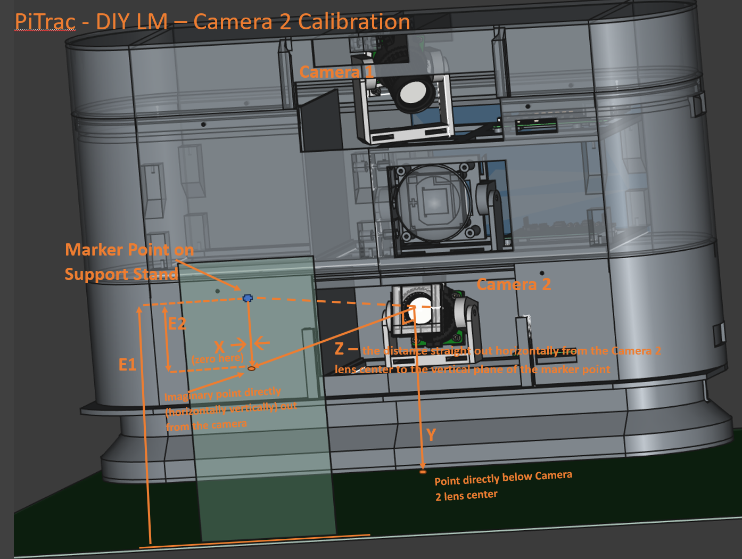
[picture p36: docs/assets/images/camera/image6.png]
       
    6. Flight Camera Measurements (values are typical/exemplary)  
    7. -X (the negative value of X) is the distance to the left (looking at the monitor) from the point on the floor directly under the center of *Flight camera* (facing the LM as a right-handed golfer) to the marker dot. ***It’s usually 0*** because the point will be centered (horizontally) in the camera’s view. Because this is relative to the OTHER camera, X will usually effectively be `~-3` or `–4` centimeters away from the other camera because the Tee camera is offset because it is twisted.    
        1. This will be made up later when we set the 
        `"kCamera2OffsetFromCamera1OriginMeters" parameter: [ **0.03**, -0.19, 0.0 ],`
        2. `X = 0.0` (typical) 
    8. Y is the distance from the center of the Flight camera lens to the level of the hitting mat (for Tee camera)  
        1. `Y = .109`  (typical)  
    9. Z is the distance ***straight out horizontally-level*** from the front of the lens to the vertical plane of the marker.  This measurement is ***not*** “as the crow flies” in a straight line from the lens to the marker point.  See pictures.  The front of the camera lens is `~1cm` back from the bottom of the base, which may be helpful if you are measuring from the bottom of the base.  
        1. `Z = .55` (typical)  
    10. E1 is the elevation from the floor or mat to the marker point in the air. Somewhat above the Y value.  
        1. `E1 = 0.16` 
    11. E2 is the elevation from Flight camera to the marker point in the air.  E2 will be entered into the PiTrac JSON configuration file as the 2nd parameter for e.g.,  `"kCamera2PositionsFromOriginMeters": [ 0.0, **-0.051,** 0.46 ]`  
        1. `E2 = E1 - Y = 0.051`.  
        2. This will help calculate the YDeg angle.  However, because of measurement inaccuracy, it may still be necessary to manually adjust that angle. [TBD]  
    12. H is the distance from the camera lens directly (as the crow flies) to the marker point.   
        1. `H = .56`
    13. In the Calibration Spreadsheet, `X_Degrees` will normally be `0` (camera facing straight out).  Conversely, `Y_Degrees = ATAN(E-Y)` and will usually be around `5` degrees (camera tilted slightly upward in order to catch fast-rising balls) (`5.3` degrees for the above example values)  
    14. Otherwise, this process same as for Tee camera, but due to the (typical) either horizontal or up-facing camera, will have to create a marker-aiming spot in mid-air by drawing on a box or something that can be propped up in front of the Flight camera  
    15. Enter the following data into the JSON file:  
        1. `"calibration.kCamera2CalibrationDistanceToBall": <Z>`  (e.g., 0.55)  
        2. `"cameras.kCamera2PositionsFromOriginMeters": [<X>, -<E2>, <Z> ]`  
        3. `"kCamera2Angles": [ <XDeg>, <YDeg, e.g. 6.3 degrees> ]`,  (from spreadsheet)  
        
----

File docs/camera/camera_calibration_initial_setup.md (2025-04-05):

---
title: Initial Setup
layout: home
parent: Calibration
nav_order: 1
---

## Camera Initial Setup

1. Use a lens-cleaning cloth and appropriate cleaning liquid to make sure the lens are spotless.  
2. If possible, make sure the Pi computers are hard-wired into the network and the network switch (if any) is turned on.  
3. Before doing anything, log into the system remotely and perform a sanity check to make sure the camera is up and running correctly.  For example, take a picture using:  
    - `PiTracCameraTools/lcGS.sh test.jpg // TODO missing` 
    - So long as a picture is taken, things are probably operating correctly.  
4. Attach a keyboard, mouse and monitor to whatever Pi Camera is being calibrated using the front and side Pi Access ports on the monitor’s walls.    
    - If your Pi is set up to display a terminal clearly on a different computer (such as using VNC viewer), you may be able to avoid this connection.  
5. If the monitor does not come up with an image after the mouse is wriggled, it may be that the system was booted at a time that the monitor was not present.  In that case, reboot.  

6. Place a small piece of transparent tape onto your monitor screen, with a dot on it so that the dot is positioned to be at the exact center of the screen.  This dot will be referred to as the “marker dot”, and its role is simply to indicate where the center of the image is.  If this dot is at the same point as some feature that the camera sees, that feature is in the center of the camera’s view. Some people will use a remote terminal program like VNC Viewer instead of connecting a monitor directly to the Pi.  In this case, just make sure that you monitor aspect ratio and any window borders will not skew the true center calibration spot.  

7. Loosen the thumb screws on the lenses (if necessary) and rotate the lens to the full-open aperture position.  For the 6mm lens in the parts list, the aperture screw is the one furthest from the camera.  Tighten the aperture screw back down and loosen the focus screw. 

----

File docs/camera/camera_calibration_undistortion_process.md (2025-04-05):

---
title: Camera Lens Undistortion Process
layout: home
parent: Calibration
nav_order: 2.3
---

## Camera Lens "Undistortion" Process

A camera lens undistortion process involves first calibrating the camera to determine the lens distortion parameters (like radial and tangential distortion coefficients), then using those parameters to mathematically map the distorted pixels in an image to their correct positions, creating an undistorted output image; this typically requires capturing images of a known pattern (like a checkerboard) to accurately calculate the distortion parameters.

Camera Calibration and Geometry. Basics of camera geometry and how it can be used to calibrate cameras. 

<iframe width="640" height="420" src="https://www.youtube.com/embed/_-BTKiamRTg" frameborder="0" allowfullscreen></iframe>

- Here is another video performing a camera calibration in OpenCV using python in VS Code: 
<iframe width="640" height="420" src="https://www.youtube.com/embed/H5qbRTikxI4" frameborder="0" allowfullscreen></iframe>

1. The undistortion code and scripts are under the `CalibrateCameraDistortions` folder.  The scripts rely upon the libcamera-still utility, so make sure that is working first.  
2. Print out a copy of the `7x10` square checker board included in that directory on a sheet of paper. Note that you want to print it to scale.  Mount the checkerboard on a piece of cardboard or slip it into a binder so that you can easily hold it and it will stay flat.    
3. When calibrating Flight camera, adding a bright incandescent light can provide additional IR light to help make the images clearer. Also, change the tuning file in the `take_calibration_shots.sh` script from:  
   1.  `--tuning-file=/usr/share/libcamera/ipa/rpi/pisp/imx296.json`  to  
   2.  `--tuning-file=/usr/share/libcamera/ipa/rpi/vc4/imx296_noir.json` (the _noir is only applicable for Flight camera)  
4. When calibrating Tee camera, ensure the room is well lit. Turning on the LED strips on the LM often produces too much light and reflection.  
5. To take the pictures, make sure your camera is focused at the distance of where the ball will be.  It’s best to have the Pi console window visible so that you can see when to move the board and avoid blurs.   
6. Next, we need a bunch of images of the checkerboard at about the distance we expect the golf ball to be imaged by the cameras.  These images should include the board in the middle and nearer the edges of the images, and must each include all of the checkerboard, not just a part of it.  
7. Sample setup   
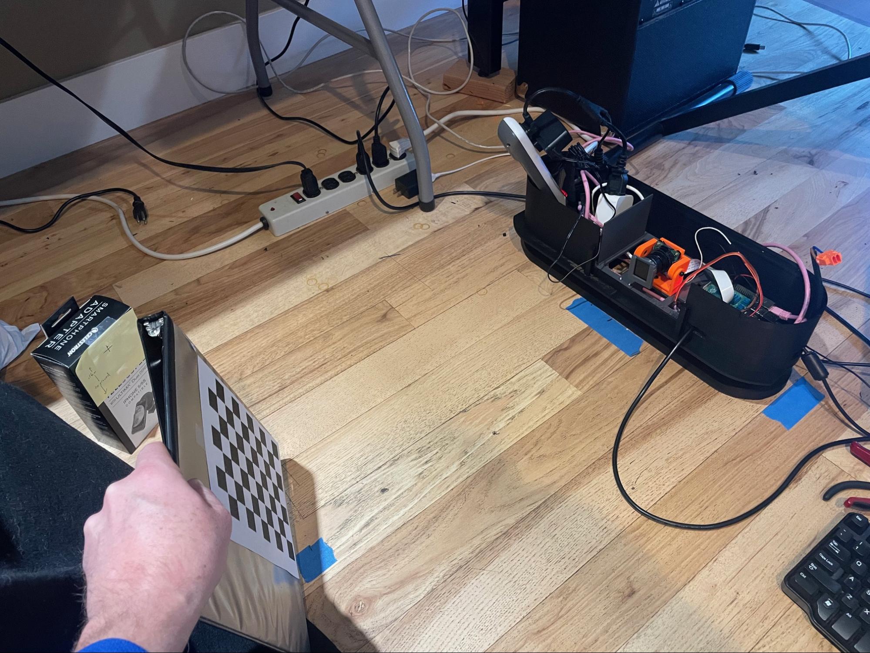
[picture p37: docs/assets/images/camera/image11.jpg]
   1.    
8. Then, run the `take_calibration_shots.sh` script, specifying, for example, `./images/cam1` as the output directory.  Twenty pictures is usually sufficient.    
   1. → `mkdir images/cam2` for flight camera 
   2. → `take_calibration_shots.sh` ./images/cam2/gs_calibation_20`  
9. The script will repeatedly pause and take a picture and save it to the output directory.  Each time the script says “READY”, quickly move the checkerboard to a new location.  Each move, try to rotate the board a little bit about the image plane so that it is in a different orientation each time.  Also, try tilting the board a little forward and back randomly.  This should result in a set of images that are named `gs_calibrate_<nn>`, where nn is an increasing number. The images should look like:  
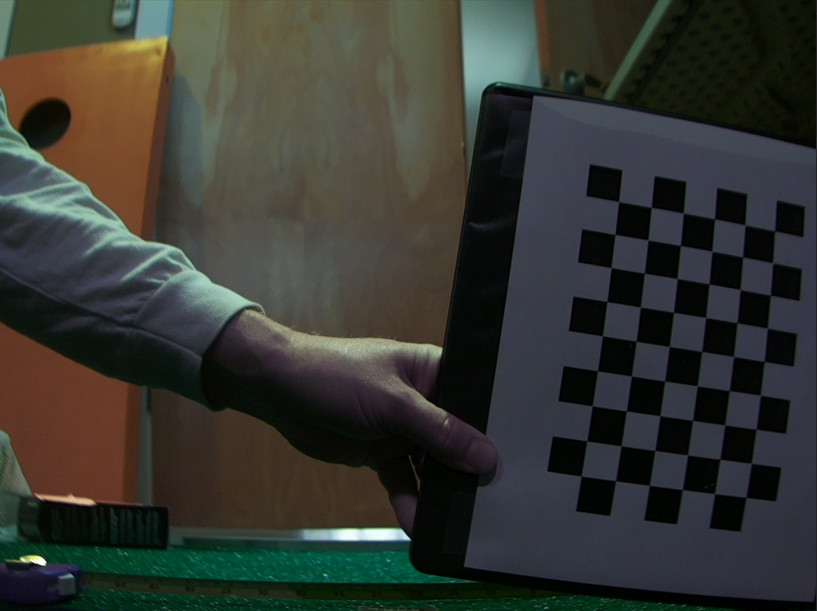
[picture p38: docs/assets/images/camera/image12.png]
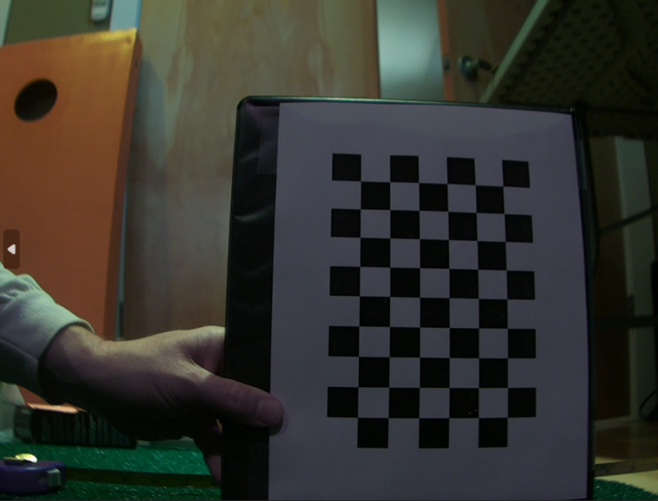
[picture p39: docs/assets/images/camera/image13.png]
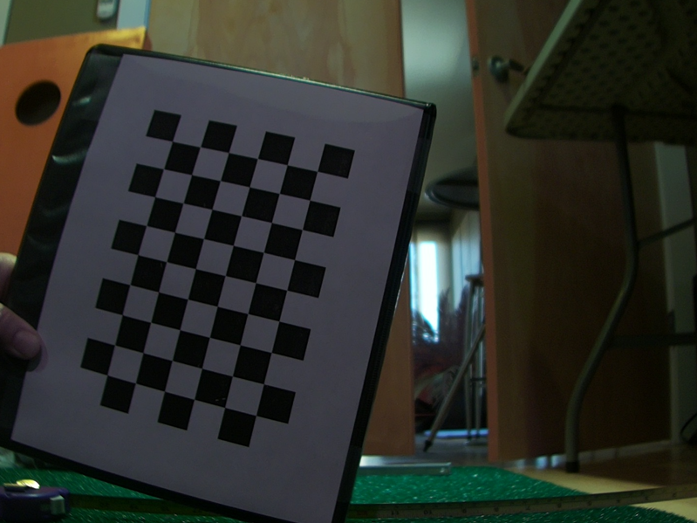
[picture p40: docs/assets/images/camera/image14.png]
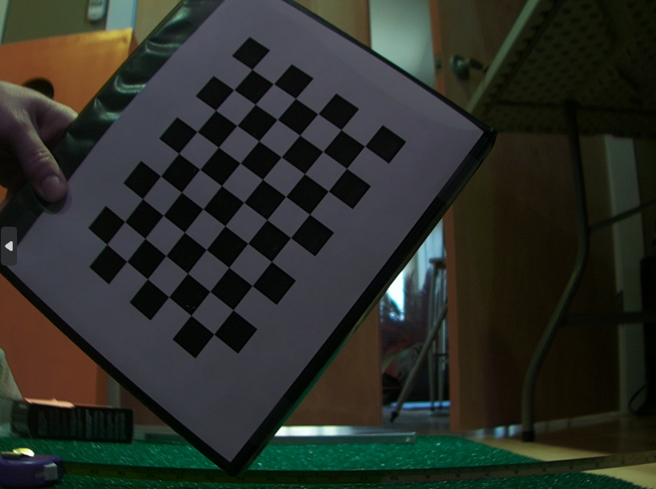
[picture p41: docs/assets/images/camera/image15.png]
10. 
11. Look through the images and delete any where the checkerboard is not fully visible.  Partially-visible board can stall the next step of this process.  
12. Now that the pictures are ready, run the python processing script on those pictures to come up with the matrices that will be necessary to setup the PiTrac configuration .json file.  To run, do:  
    1. First, edit the python script to point to the images just gathered, for example:  
       1. `images = glob.glob('./images/cam1/*.png')` 
    2. → `rm caliResult*.png` (to remove any earlier calibration sanity-check files)  
    3. Pick an output image to use as a test case:  
       1. `cp images/cam2/gs_calibation_1.png` `test_image_for_undistortion.png`  
    4. → `python CameraCalibration.py`  
    5. Alternatively, there is a Visual Studio .sln solution file that you can open up in Studio to step through the code if there is a problem.  
13. After processing, there will be several files output to the current working directory.  If you compare `test_image_for_undistortion` and `caliResult2.png`, you can see the before and after results of applying the computed un-distortion matrices.  The un-distorted picture should have each checkerboard square look the same size and they should look square, not rounded.  The lines of rows and columns should be straight in the undistorted image.  caliResult1.png shows how the original image is “warped” to un-distort it  
14. If that looks good, take the information in the files `distortion.txt` and `cameraMatrix.txt` and copy the values into the two parameters below (changing `Camera2` (Flight camera) for `Camera1` (Tee camera) if this is for Flight camera).  These parameters are in the “cameras” subsection of `golf_sim_config.json`:  

    ``` json
    "kCamera1CalibrationMatrix": [ 
    [ 1.748506644661262953e+03, 0.000000000000000000e+00, 6.325374407393054526e+02 ],  
    [ 0.000000000000000000e+00, 1.743341748687922745e+03, 4.075677927449370941e+02 ],  
    [ 0.000000000000000000e+00, 0.000000000000000000e+00, 1.000000000000000000e+00 ]],  
    ```
    `"kCamera1DistortionVector": [  -0.504763   0.173410   0.001554   0.000916   0.355220 ]`,

15. Do the same for Tee camera and Flight camera

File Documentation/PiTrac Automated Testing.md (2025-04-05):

**PiTrac Automated Testing**

This document describes how to setup PiTrac’s automated testing.

PiTrac’s automated testing supports the comparison of final ball results (velocity, back-spin, etc.) computed from the teed-ball and strobed images, to a set of expected values from a comma-separated file.  The expected values are typically generated by another launch monitor that was used in conjunction with PiTrac to provide “ground-truth” data against which to compare PiTrac results.  Alternatively, the expected data can be computed manually with a good eye, an on-screen protractor, and a little algebra.

**How to setup for automated testing:**  
To prepare a test suite (a set of result and expected value sets), create a directory that contains the following (details further below):

1. An “expected values” file corresponding to expected values for each of the primary shot value elements for each (numbered) shot.  
2. Image files (from the diagnostic image outputs of PiTrac) that correspond to the teed-ball and strobed ball images for each of the shots in the expected value file.  These are the images that were taken by PiTrac when the ground-truth data was determined.  To tie the testing together, each filename must contain a shot number corresponding to each line of the expected values file as well as a certain prefix.  Only one pair of images can have the same shot number.  For example, with “\*” representing any other text, the pattern of image pairs look like:

   1. gs\_log\_img\_\_log\_ball\_final\_found\_ball\_img\_Shot\_1\_\*.png  
   2. gs\_log\_img\_\_log\_cam2\_last\_strobed\_img\_Shot\_1\_\*.png

   The Image files are produced by PiTrac automatically when the "logging": "kLogDiagnosticImagesToUniqueFiles": is set to 1\.  For example, the following files are examples of those produced corresponding to the picture of the teed-up ball and the picture of the strobed balls, repsectively.  These are the files that are necessary to test each shot:

   3. gs\_log\_img\_\_log\_ball\_final\_found\_ball\_img\_Shot\_1\_2025-Feb-07\_11.03.49.png  
   4. gs\_log\_img\_\_log\_cam2\_last\_strobed\_img\_Shot\_1\_2025-Feb-07\_11.03.12.png

3. The golf\_sim\_config.json file that was used when the images and data in the test suite were generated.  Keeping a copy of the .json file here will ensure that when other values change later, you can always reproduce the setup that was used when the images were generated.

Next, set the file directory name and the names of the input (expected values) file and output file into the config file.  Specifically, set tolerances, input and output files and the test directory as follows in an example golf\_sim\_config.json file:

"testing": {  
…  
	"kAutomatedTestSuiteDirectory": "M:/Dev/PiTrac/Software/LMSourceCode/Testing/TestSuite\_2025\_02\_07/",  
	"kAutomatedTestExpectedResultsCSV": "Uneekor Comparison 2025-02-07\_Small\_Test.csv",  
	"kAutomatedTestResultsCSV": "PiTrac\_Test\_Results.csv",  
	"kAutomatedTestToleranceBallSpeedMPH": 4,  
	"kAutomatedTestToleranceHLA": 3,  
	"kAutomatedTestToleranceVLA": 2,  
	"kAutomatedTestToleranceBackSpin": 250,  
	"kAutomatedTestToleranceSideSpin": 300,

The tolerances are the value that–above which–the difference between PiTrac’s number and the expected results file will result in the test being considered a failure.

Finally, make sure that PiTrac–when run–will use the same golf\_sim\_config.json file that is stored in the test suite directory.

The format of the expected-values input .csv file is as follows, but with commas between the values.  Shown below first is how the file would look in Excel, and then the raw file:

Shot	Speed	VLA	HLA	Back Spin	Side Spin	Ignore  
1	66.6	19.1	\-5.6	3987		\-355		FALSE  
2	54.5	10.9	\-4	1686		\-1048		TRUE  
3	60.5	14.5	\-5.5	2137		\-1421		FALSE

So, in raw format:  
Shot,Speed,VLA,HLA,Back Spin,Side Spin,Ignore  
1,66.6,19.1,-5.6,3987,-355,  
2,54.5,10.9,-4,1686,-1048,TRUE  
3,60.5,14.5,-5.5,2137,-1421,

If “Ignore” is set to TRUE, the automated testing will skip over that shot.  This can be useful when you know that certain images did not really work out (perhaps because of interference from an external strobing system).  The input .csv file should be easy to create from the output of most golf sims.  If your sim uses Left and Right side spin designators, an Excel formula like the following will work to convert to the signed integer format used by the PiTrac .csv file  (for example for Cell K5 in a different spreadsheet called “Uneekor”:

\=IF(LEFT(Uneekor\!K5,1)="R",1,-1)\*NUMBERVALUE((RIGHT(LEFT(Uneekor\!K5,LEN(Uneekor\!K5)-1),4)))

**How to run automated testing:**  
To run the test to process the image files and compare the computed ball-shot results to the expected results, you can run PiTrac in either Linux or Windows.  Running in Windows under Visual Studio may help in debugging any problems.  When running PiTrac, use the mode in the following example,, and (generally) info-level logging:

pitrac \--show\_images 1  \--base\_image\_logging\_dir L:\\ \--lm\_comparison\_mode=1 **\--logging\_level info**  \--artifact\_save\_level=all \--wait\_keys 0 **\--system\_mode automated\_testing**  \--search\_center\_x 800  \--search\_center\_y 550

Generally, the images that will be used will be images generated when PiTrac was running alongside another tracking system.  If the other tracking system uses IR strobing (like a Uneekor Eye XO, for example), you will want to set “\-lm\_comparison\_mode=1” to try to compensate for the brighter resulting images.

The output .csv file (which will be named as the value in kAutomatedTestResultsCSV) has the following format:

Shot ID		Comparison (PiTrac value minus Uneekor)						System Data																	  
Ball	 PiTrac Shot	 Speed ? (mph)	 VLA ? 	 HLA ? °	 Back Spin ? (rpm)	 Side Spin ? (rpm)	 	 Uneekor Speed	 PiTrac Speed	 	 Uneekor VLA°	 PiTrac VLA°	 	 Uneekor HLA°	 PiTrac HLA°	 	 Uneekor Back Spin	 PiTrac Back Spin	 	 Uneekor Side Spin	 PiTrac Side Spin	 	 Ball ID Picture	 Spin Ball 1	 Spin Ball 2  
	1	\-2.58109	0.218401	\-0.980485	\-336	\-1073	 	66.6	64.0189	 	19.1	18.1195	 	\-5.6	\-5.3816	 	3987	3650.79	 	\-355	\-1428.57	FAIL			  
 	 	 	 															  
	2																								  
	3	\-3.91849	\-2.07088	\-0.631305	\-602	\-60	 	60.5	56.5815	 	14.5	13.8687	 	\-5.5	\-7.57088	 	2137	1534.39	 	\-1421	\-1481.48	FAIL

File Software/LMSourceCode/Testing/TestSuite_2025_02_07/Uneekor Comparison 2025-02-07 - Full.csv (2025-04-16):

Shot | Speed | VLA | HLA | Back Spin | Side Spin
1 | 68.1 | 21.1 | -3.7 | 5136 | -668
2 | 66.6 | 19.1 | -5.6 | 3987 | -355
3 | 72.8 | 2.3 | 1.9 | 2002 | 1942
4 | 54.5 | 10.9 | -4.0 | 1686 | -1048
5 | 35.2 | 7.0 | 5.0 | -3718 | 581
6 | 72.6 | 9.9 | -4.4 | 3226 | -953
7 | 75.3 | 18.5 | -6.9 | 4880 | -85
8 | 78.7 | 18.7 | -5.1 | 4507 | -279
9 | 57.1 | 30.3 | -4.9 | 4255 | -202
10 | 62.9 | 23.0 | -12.1 | 3569 | -2235
11 | 65.4 | 13.0 | -9.7 | 1417 | -2072
12 | 70.4 | 11.1 | 2.8 | 1169 | 346
13 | 72.4 | 21.0 | -3.2 | 5707 | -1322
14 | 71.7 | 16.3 | -6.6 | 2138 | -801
15 | 77.4 | 20.7 | -4.6 | 4737 | -418
16 | 76.8 | 5.7 | 4.3 | 2477 | 1417
17 | 64.4 | 17.6 | 3.4 | 3895 | 718
18 | 41.5 | 7.0 | 2.2 | -3610 | 403
19 | 73.7 | 15.1 | 2.8 | 3969 | 978
20 | 71.0 | 22.2 | 4.8 | 4797 | 809
21 | 78.3 | 21.8 | 2.2 | 5532 | 1196
22 | 72.1 | 16.2 | -4.2 | 2068 | -642
23 | 64.0 | 17.6 | 0.4 | 2648 | 375
24 | 60.8 | 16.2 | 1.7 | 2532 | 472
25 | 60.5 | 14.5 | -5.5 | 2137 | -1421
26 | 77.8 | 20.1 | -3.1 | 4558 | -275
27 | 76.4 | 20.7 | 0.4 | 4081 | 97
28 | 70.2 | 19.6 | -1.9 | 4097 | -379
29 | 73.4 | 20.5 | -1.2 | 4403 | -951
30 | 79.2 | 20.3 | -2.1 | 5377 | -680
31 | 59.3 | 20.7 | 7.0 | 4419 | 1671
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

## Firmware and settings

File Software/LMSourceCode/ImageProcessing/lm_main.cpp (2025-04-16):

/* SPDX-License-Identifier: GPL-2.0-only */
/*
 * Copyright (C) 2022-2025, Verdant Consultants, LLC.
 */

// ImageProcessing.cpp { This file contains the main test function. Program execution begins and ends there.
//

#include <boost/timer/timer.hpp>

#include <opencv2/calib3d/calib3d.hpp>

#include <iostream>
#include <cstring>
#include <filesystem>

#include "gs_globals.h"
#include "golf_ball.h"
#include "gs_options.h"
#include "gs_gspro_results.h"
#include "gs_ui_system.h"
#include "gs_config.h"
#include "gs_results.h"
#include "gs_camera.h"

#include "logging_tools.h"
#include "colorsys.h"
#include "ball_image_proc.h"
#include "cv_utils.h"
#include "gs_camera.h"
#include "gs_config.h"
#include "pulse_strobe.h"


#include "gs_gspro_results.h"
#include "gs_gspro_test_server.h"
#include "gs_gspro_response.h"
#include "gs_sim_interface.h"
#include "gs_e6_interface.h"
#include "gs_automated_testing.h"

#include "gs_fsm.h"
#include "gs_ipc_system.h"
#include "libcamera_interface.h"


namespace fs = std::filesystem;

using namespace golf_sim;

const double kLocationTolerancePercent = 10;


// The result files we create will be prefixed with this
static constexpr std::string_view TEST_IMAGE_PREFIX = "TEST_RESULT_GetBall_";

std::string kBaseTestDir = "Will be set from the .json configuration file";


BallImageProc *get_image_processor() {
    BallImageProc  *ip = new BallImageProc;
    // TBD - Setup as necessary
    return ip;
}


void test_image(std::string_view subdir, std::string_view filename) {
    BOOST_LOG_FUNCTION();

    fs::path dir(subdir);
    fs::path file(filename);
    fs::path fullPath = dir / file;
    std::string fname = fullPath.generic_string();

    GolfBall ball;

    boost::to_lower(fname);
    size_t i = fname.find("clr-");

    std::string color;
    if (i > 0) {
        color = fname.substr(i);
    }

    if (!color.empty()) {

        boost::to_lower(color);

        if (color.find("white") > 0) {
            ball.ball_color_ = GolfBall::BallColor::kWhite;
        }
        else if (color.find("orange") > 0) {
            ball.ball_color_ = GolfBall::BallColor::kOrange;
        }
        else if (color.find("yellow") > 0) {
            ball.ball_color_ = GolfBall::BallColor::kYellow;
        }
        else if (color.find("green") > 0) {
            ball.ball_color_ = GolfBall::BallColor::kOpticGreen;
        }
        else {
            // For this part of our test suite, if there is no specified color, white(not kUnknown) is our best bet
            ball.ball_color_ = GolfBall::BallColor::kWhite;
        }
    }

    BallImageProc *ip = get_image_processor();

    cv::Mat img = cv::imread(fname, cv::IMREAD_COLOR);
    ip->image_name_ = fname;

    cv::Rect nullROI;
    std::vector<GolfBall> return_balls;
    bool result = ip->GetBall(img, ball, return_balls, nullROI, BallImageProc::BallSearchMode::kFindPlacedBall );

    if (!result || return_balls.empty()) {
        GS_LOG_MSG(error, "GetBall() failed to get a ball.");
        return;
    }

    GolfBall result_ball = return_balls.front();

    // If there were any debugging windows, get rid of them now
    cv::destroyAllWindows();

    // Create a single output file with the result overlaid on the original image, along with
    // whatever other debug images that we want.

    /******  THIS FUNCTION SHOULD BE DELETED - TBD 
    cv::Mat outputImage;

    auto ncFinalArray = nc::NdArray<nc::uint8>(ip->final_result_image_.data, ip->final_result_image_.rows, ip->final_result_image_.cols);
    auto ncCandidatesArray = nc::NdArray<nc::uint8>(ip->candidates_image_.data, ip->candidates_image_.rows, ip->candidates_image_.cols);
    auto ncOutputImage = nc::hstack({ ncFinalArray, ncCandidatesArray });

    outputImage = CvUtils::ConvertNDArrayToMat(ncOutputImage);

    fs::path outputDir(subdir);
    fs::path outputFile(std::string(TEST_IMAGE_PREFIX).append(filename));
    fs::path outputFullPath = outputDir / outputFile;
    std::string outputFileName = outputFullPath.generic_string();

    cv::imwrite(outputFileName, outputImage);

    LoggingTools::ShowImage(fname, outputImage);
    ****/
}

void test_certain_images() {

    test_image("./Images/", "FakePiCameraPhotoOfGolfBall-Clr-Green-Flat.png");
    test_image("./Images/", "WedgeNextToOrangeBall-Clr-Orange.png");
    test_image("./Images/", "FirstPiV1CamBall-Clr-Yellow.jpeg");
    test_image("./Images/", "AboutToBeHitLoRes-Clr-White.jpg");
    test_image("./Images/", "JustHitByIronToRight-Clr-White.png");
    test_image("./Images/", "JustHitSlightBlurClub-Clr-White.png");
    test_image("./Images/", "WedgeNextToOrangeBall-Clr-Orange.jpg");
    test_image("./Images/", "HitClubGoneWithFlyingTee-Clr-White.png");
    test_image("./Images/", "IMG_7713-Clr-Yellow.jpg");
}



void WalkDirectoryTree(const fs::path& pathToScan, int level = 0) {
    for (const auto& entry : fs::directory_iterator(pathToScan)) {
        const auto filenameStr = entry.path().filename().string();
        if (entry.is_directory() && (filenameStr.find("IGNORE") != std::string::npos) ) {
            // Recurse to any sub-directories
            WalkDirectoryTree(entry, level + 1);
        }
        else if (entry.is_regular_file()) {
            if (((filenameStr.find(".png") > 0) &&
                (filenameStr.find(".jpg") > 0) &&
                (filenameStr.find(".jpeg") > 0)) &&
                ((filenameStr.find("IGNORE") == std::string::npos) &&
                    (filenameStr.find("TEST_IMAGE_PREFIX") == std::string::npos))
                ) {
                test_image(pathToScan.generic_string(), filenameStr);
            }
        }
        else
            std::cout << "(ignoring)" << filenameStr << "\n";
    }
}

void test_all_test_files() {
//    std::string rootdir = "D:/GolfSim/C++Code/GolfSim/ImageProcessing/Images";
    std::string rootdir = "D:/GolfSim/TestPictures";


    WalkDirectoryTree(rootdir);
}

void test_calibrated_location(std::string twoFootImgName, std::string threeFootImgName, std::string fourFootImgName) {
    
    cv::Mat img = cv::imread(twoFootImgName);
    LoggingTools::ShowImage(twoFootImgName, img);

    // Test of the GetCalibratedBall function
    GolfSimCamera c;
    GolfBall b;

    std::vector<cv::Vec3d> camera_positions_from_origin = std::vector<cv::Vec3d>({ GolfSimCamera::kCamera1PositionsFromExpectedBallMeters, GolfSimCamera::kCamera2PositionsFromExpectedBallMeters });
    bool success = c.GetCalibratedBall(c, img, b);

    // Now, test the calibration by seeing if the same ball can be found using the calibrated ball
    GS_LOG_TRACE_MSG(trace, "GET BALL LOCATION AGAIN FOR 2 FEET");
    GolfBall newBall;
    success = c.GetCurrentBallLocation(c, img, b, newBall);

    if (!threeFootImgName.empty()) {
        // This original HSV masking range from the calibration is not working well.Try a lower H ?
        // b.ball_hsv_range_ = [(0, 0, 175), (175, 102, 255)]
        GS_LOG_TRACE_MSG(trace, "GET BALL LOCATION FOR 3 FEET");
        img = cv::imread(threeFootImgName);

        // TBD - Consider the fact that the ball should be no larger than the radius of the last found
        // ball, and should have that ball"s average color
        success = c.GetCurrentBallLocation(c, img, b, newBall);
        // TBD _ FIX b.average_color_, b.median_color_, b.std_color_ = cu.GetBallColorRgb(c.img, newBall.ball_circle_)
    }

    if (!fourFootImgName.empty()) {
        GS_LOG_TRACE_MSG(trace, "GET BALL LOCATION FOR 4 FEET");
        img = cv::imread(fourFootImgName);
        success = c.GetCurrentBallLocation(c, img, b, newBall);
    }
}



bool testProjection() {

    cv::Mat ball1Img, ball2Img;
    GolfBall ball1, ball2;


    std::string kBaseTestDir = "D:\\GolfSim\\C++Code\\GolfSim\\ImageProcessing\\";


    // We prefer the command-line setting even if there's one in the .json config file
    if (!GolfSimOptions::GetCommandLineOptions().base_image_logging_dir_.empty()) {
        kBaseTestDir = GolfSimOptions::GetCommandLineOptions().base_image_logging_dir_;
    }
    else {
        // Attempt to get the image logging directory from the .json config file
#ifdef __unix__
        GolfSimConfiguration::SetConstant("gs_config.logging.kLinuxBaseImageLoggingDir", kBaseTestDir);
#else
        GolfSimConfiguration::SetConstant("gs_config.logging.kPCBaseImageLoggingDir", kBaseTestDir);
#endif
    }


    const std::string k0_DegreeBallFileName_00 = kBaseTestDir + "test_ball_masked_0_deg_dulled.png";
    const std::string k45_DegreeBallFileName_00 = kBaseTestDir + "test_ball_masked_45_deg_dulled.png";

    ball1Img = cv::imread(k0_DegreeBallFileName_00, cv::IMREAD_COLOR);
    ball2Img = cv::imread(k45_DegreeBallFileName_00, cv::IMREAD_COLOR);

    /*
    gfilters = create_gaborfilter()
    image_g = apply_filter(myimage, gfilters)
    
    min_interval = 120
    max_interval = 250
    image_edge_g = cv2.Canny(image_g, min_interval, max_interval)

    // Create a simple matrix of 3D points
    // cv::Mat<> test3DPoints{ {0,0,1} }

    std::vector<cv::Point3i> test2DPoints{ {0,0,1}, {1,0,0} };
    */
    return true;
}

void showVisualization() {
    /* TBD - probably too much work to get Viz working 
    ///Createawindow 
    viz::Viz3dmyWindow("VizDemo"); 
    ///Starteventloop 
    myWindow.spin();

    ///Eventloopisoverwhenpressedq,Q,e,E cout<<"Firsteventloopisover"<<endl; 
    ///Accesswindowviaitsname 
    viz::Viz3dsameWindow=viz::getWindowByName("VizDemo"); 
    /// ///Starteventloop 
    sameWindow.spin(); 
    /// ///Eventloopisoverwhenpressedq,Q,e,E
    cout<<"Secondeventloopisover"<<endl;
    /// ///Eventloopisoverwhenpressedq,Q,e,E
    /// ///Starteventlooponcefor1millisecond
    sameWindow.spinOnce(1,true);

    while (!sameWindow.wasStopped()) {
        ///Interactwithwindow

        ///Eventloopfor1millisecond
        sameWindow.spinOnce(1,true);
    }
    */
}


bool testSpinDetection() {

    /*
    const std::string k0_DegreeBallFileName_00 = "test_ball_spin_strong_landmarks_00d_3280w_bright_00.png";
    const std::string kUnknown_DegreeBallFileName_00 = "test_ball_spin_strong_landmarks_14d_3280w_bright_00.png";

    const std::string k0_DegreeBallFileName_00 = "test_ball_spin_strong_landmarks_00d_2592w_bright_01.png";
    const std::string kUnknown_DegreeBallFileName_00 = "test_ball_spin_strong_landmarks_08d_2592w_bright_01.png";

    const std::string k0_DegreeBallFileName_00 = "test_ball_spin_strong_landmarks_00d_2592w_bright_00.png";
    const std::string kUnknown_DegreeBallFileName_00 = "test_ball_spin_strong_landmarks_45d_2592w_bright_00.png";

    const std::string k0_DegreeBallFileName_00 = k"test_ball_spin_strong_landmarks_00d_2592w_bright_01.png";
    const std::string kUnknown_DegreeBallFileName_00 = "test_ball_spin_strong_landmarks_35d_2592w_bright_01.png";

    const std::string k0_DegreeBallFileName_00 = "test_ball_spin_strong_landmarks_00d-x_3280w_bright_02.png";
    const std::string kUnknown_DegreeBallFileName_00 = "test_ball_spin_strong_landmarks_15d-x_3280w_bright_02.png";

    const std::string k0_DegreeBallFileName_00 = "test_ball_spin_st-landmarks_rand_1st_3280w_bright_04.png";
    const std::string kUnknown_DegreeBallFileName_00 = k"test_ball_spin_st-landmarks_rand_2nd_3280w_bright_04.png";

    const std::string k0_DegreeBallFileName_00 = "test_pos_2592w_BASE6off_22Dist_00inz_00degx_00iny_00.png";
    const std::string kUnknown_DegreeBallFileName_00 = "test_pos_2592w_6off_22Dist_10inz_30degx_.75iny_00.png";

    const std::string k0_DegreeBallFileName_00 = "test_ball_spin_strong_landmarks_00d_2592w_bright_00.png";
    const std::string kUnknown_DegreeBallFileName_00 = "test_ball_spin_strong_landmarks_45d_2592w_bright_00.png";
   */

    const std::string k0_DegreeBallFileName_00 = "strobed_spin_test_0z_ctr_02.png";
    const std::string kUnknown_DegreeBallFileName_00 = "strobed_spin_test_30z_-30x_ctr_02.png";
    // const std::string kUnknown_DegreeBallFileName_00 = "loc_test_20_degree_right_strobed.png";
    // NEEDS TO BE CORRECTED FOR EACH TEST -  Assume only 1 camera for now, so all deltas are 0
    // In meters
    std::vector<cv::Vec3d> camera_positions_from_origin = std::vector<cv::Vec3d>({ GolfSimCamera::kCamera1PositionsFromExpectedBallMeters, GolfSimCamera::kCamera2PositionsFromExpectedBallMeters });


    cv::Mat ball1ImgGray;
    cv::Mat ball2ImgGray;
    cv::Mat ball1ImgColor;
    cv::Mat ball2ImgColor;

    CameraHardware::CameraModel  cameraModel = CameraHardware::PiGSCam6mmWideLens;

    if (!GsAutomatedTesting::ReadTestImages(k0_DegreeBallFileName_00, kUnknown_DegreeBallFileName_00, ball1ImgGray, ball2ImgGray, ball1ImgColor, ball2ImgColor, cameraModel, false /*No Undistort*/)) {
        GS_LOG_TRACE_MSG(trace, "Failed to read valid images.");
        return false;
    }

    // Get the ball data.  We will calibrate based on the first ball and then get the second one
    // using that calibrated data from the first ball.
    
    GolfSimCamera c;
    c.camera_hardware_.init_camera_parameters(GsCameraNumber::kGsCamera1, cameraModel);

    GolfBall ball1, ball2;

    c.camera_hardware_.firstCannedImageFileName = kBaseTestDir + k0_DegreeBallFileName_00;
    c.camera_hardware_.firstCannedImage = ball1ImgColor;

    cv::Vec2i expectedBallCenter = cv::Vec2i(1456 / 3, 1088 / 2);

    if (GolfSimOptions::GetCommandLineOptions().search_center_x_ > 0) {
        expectedBallCenter[0] = GolfSimOptions::GetCommandLineOptions().search_center_x_;
    }

    if (GolfSimOptions::GetCommandLineOptions().search_center_y_ > 0) {
        expectedBallCenter[1] = GolfSimOptions::GetCommandLineOptions().search_center_y_;
    }


    bool success = c.GetCalibratedBall(c, ball1ImgColor, ball1, expectedBallCenter);

    if (!success) {
        GS_LOG_TRACE_MSG(trace, "Failed to GetCalibratedBall.");
        return false;
    }
    c.camera_hardware_.firstCannedImageFileName = kBaseTestDir + k0_DegreeBallFileName_00;
    c.camera_hardware_.secondCannedImageFileName = kBaseTestDir + kUnknown_DegreeBallFileName_00;
    c.camera_hardware_.firstCannedImage = ball1ImgColor;
    c.camera_hardware_.secondCannedImage = ball2ImgColor;

    success = c.GetCurrentBallLocation(c, ball2ImgColor, ball1, ball2);

    if (!success) {
        GS_LOG_TRACE_MSG(trace, "Could not find 2nd ball");
        return false;
    }

    boost::timer::cpu_timer timer1;

    cv::Vec3d rotationResults = BallImageProc::GetBallRotation(ball1ImgGray, ball1, ball2ImgGray, ball2);

    timer1.stop();
    boost::timer::cpu_times times = timer1.elapsed();
    std::cout << "BallImageProc::GetBallRotation: ";
    std::cout << std::fixed << std::setprecision(8)
        << times.wall / 1.0e9 << "s wall, "
        << times.user / 1.0e9 << "s user + "
        << times.system / 1.0e9 << "s system.\n";

    // TBD - Now implemented in the GetBallRotation() function.  See how the original image would look if rotated as the GetBallRotation function calculated

    std::string s = "Ball Rotation (degrees):  X: " + std::to_string(rotationResults[0]) + "\tY: " + std::to_string(rotationResults[1]) + "\tZ: " + std::to_string(rotationResults[2]) + "\n";

    return true;
}



bool TestSpin() {

    GolfBall ball1;
    GolfBall ball2;
    cv::Mat img1;
    cv::Mat img2;

    GS_LOG_MSG(info, "TestSpin is in process.");
    GS_LOG_TRACE_MSG(trace, "Please position the ball for a first image and hit any key.");

    int keyPressed = cv::waitKey(0) & 0xFF;

#ifdef __unix__   

    // Find the first ball.  This will cause a pause to view the image
    // that will allow the user to reposition the ball for a second time
    if (!CheckForBall(ball1, img1)) {
        GS_LOG_TRACE_MSG(trace, "Failed to CheckForBall.");
        return false;
    }

    GS_LOG_TRACE_MSG(trace, "Position the ball for a second image and hit any key.");

    if (!CheckForBall(ball2, img2)) {
        GS_LOG_TRACE_MSG(trace, "Failed to CheckForBall.");
        return false;
    }

    LoggingTools::LogImage("test_spin_img_ball1", img1, std::vector < cv::Point >{}, true);
    LoggingTools::LogImage("test_spin_img_ball2", img2, std::vector < cv::Point >{}, true);

    cv::Mat grayImage1;
    cv::Mat grayImage2;
    cv::cvtColor(img1, grayImage1, cv::COLOR_BGR2GRAY);
    cv::cvtColor(img2, grayImage2, cv::COLOR_BGR2GRAY);

    cv::Vec3d rotationResults = BallImageProc::GetBallRotation(grayImage1, ball1, grayImage2, ball2);
#endif

    return true;
}

bool testAnalyzeStrobedBalls() {

    // Have to call this here because we are not starting the FSM, but need (simulated) pulse information
    PulseStrobe::InitGPIOSystem();

    std::string kTwoImageTestTeedBallImage;
    std::string kTwoImageTestStrobedImage;
    std::string kTwoImageTestPreImage;

    GolfSimConfiguration::SetConstant("gs_config.testing.kTwoImageTestTeedBallImage", kTwoImageTestTeedBallImage);
    GolfSimConfiguration::SetConstant("gs_config.testing.kTwoImageTestStrobedImage", kTwoImageTestStrobedImage);
    GolfSimConfiguration::SetConstant("gs_config.testing.kTwoImageTestPreImage", kTwoImageTestPreImage);

    const std::string kTestCamImageFileName_00 = kTwoImageTestTeedBallImage;
   
    const std::string kTestCam2StrobedmageFileName = kTwoImageTestStrobedImage;

    cv::Mat ball1ImgGray;
    cv::Mat ball2ImgGray;
    cv::Mat ball1ImgColor;
    cv::Mat ball2ImgColor; 

    CameraHardware::CameraModel  cameraModel = CameraHardware::PiGSCam6mmWideLens;

    if (!GsAutomatedTesting::ReadTestImages(kTestCamImageFileName_00, kTestCam2StrobedmageFileName, ball1ImgGray, ball2ImgGray, ball1ImgColor, ball2ImgColor, cameraModel,false /*No Undistort*/)) {
        GS_LOG_TRACE_MSG(trace, "Failed to read valid images.");
        return false;
    }

    cv::Mat camera2_pre_image_color;
    /****  NO LONGER USED
    // Also read the test  pre-image
    std::string preImageFileName = kBaseTestDir + kTwoImageTestPreImage;

    GS_LOG_TRACE_MSG(trace, "Pre Image1: " + preImageFileName);

    camera2_pre_image_color = cv::imread(preImageFileName, cv::IMREAD_COLOR);

    if (camera2_pre_image_color.empty()) {
        return false;
    }
    ***/

    GolfBall result_ball;
    cv::Vec3d rotation_results;
    cv::Mat exposures_image;
    std::vector<GolfBall> exposure_balls;

    if (!GolfSimCamera::ProcessReceivedCam2Image(ball1ImgColor, 
                                                 ball2ImgColor, 
                                                 camera2_pre_image_color, 
                                                 result_ball, 
                                                 rotation_results, 
                                                 exposures_image, 
                                                 exposure_balls)) {
        GS_LOG_MSG(error, "Failed ProcessReceivedCam2Image.");
        return false;
    }

#ifdef __unix__  // Ignore in Windows environment
    GsUISystem::SaveWebserverImage("kCameraXBallLocation_", ball1ImgColor, exposure_balls);
#endif
    GsGSProResults results(result_ball);
    GS_LOG_TRACE_MSG(trace, "Results are: " + results.Format());

    PulseStrobe::DeinitGPIOSystem();

    return true;
}
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
int main(int argc, char *argv[])
{
    try {
        if (!GolfSimOptions::GetCommandLineOptions().Parse(argc, argv))
        {
            GS_LOG_MSG(error, "Could not GetCommandLineOptions.  Exiting.");
            return 0;
        }

	// If we're just showing the help information, that's already been
	// done when we called parse.  So just exit.
	if (GolfSimOptions::GetCommandLineOptions().help_)
	{
		return 1;
	}

        LoggingTools::InitLogging();

        GS_LOG_MSG(info, "Golf Sim Launch Monitor Started");

        GolfSimOptions::GetCommandLineOptions().Print();

        std::string config_file_name = "golf_sim_config.json";

        if (!GolfSimOptions::GetCommandLineOptions().config_file_.empty()) {
            config_file_name = GolfSimOptions::GetCommandLineOptions().config_file_;
        }

        if (!GolfSimConfiguration::Initialize(config_file_name)) {
            GS_LOG_MSG(error, "Could not initialize configuration module using config file: " + config_file_name + ".  Exiting.");
            return 0;
        }

        LoggingTools::logging_tool_wait_for_keypress_ = GolfSimOptions::GetCommandLineOptions().wait_for_key_on_images_;

        // We prefer the command-line setting even if there's one in the .json config file
        if (!GolfSimOptions::GetCommandLineOptions().base_image_logging_dir_.empty()) {
            kBaseTestDir = GolfSimOptions::GetCommandLineOptions().base_image_logging_dir_;
        }
        else {
            // Attempt to get the image logging directory from the .json config file
#ifdef __unix__
            GolfSimConfiguration::SetConstant("gs_config.logging.kLinuxBaseImageLoggingDir", kBaseTestDir);
#else
            GolfSimConfiguration::SetConstant("gs_config.logging.kPCBaseImageLoggingDir", kBaseTestDir);
#endif
        }
        // If the configuration file forgot to add a "/" at the end of the logging directory, we should add it here ourselves
        if (kBaseTestDir.back() != '/') {
            kBaseTestDir += '/';
        }


        // TBD - consider if there is a better place for this?
        GolfSimGlobals::golf_sim_running_ = true;

        run_main(argc, argv);
    }
    catch (std::exception const& e)
    {
        GS_LOG_MSG(error, "Exception occurred. ERROR: *** " + std::string(e.what()) + " ***");
        return false;
    }

    GS_LOG_TRACE_MSG(trace, "Finished run_main.");
    
    // GS_LOG_TRACE_MSG(trace, "Waiting for any keypress to end program.");
    // cv::waitKey(0);

    GS_LOG_TRACE_MSG(trace, "Tests Complete");
}

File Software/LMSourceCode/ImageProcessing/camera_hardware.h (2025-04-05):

/* SPDX-License-Identifier: GPL-2.0-only */
/*
 * Copyright (C) 2022-2025, Verdant Consultants, LLC.
 */

// Attempts to hide some details about the specific camera hardware in use.
// Coding for any new cameras should start here

#pragma once

#include <string>
#include "logging_tools.h"
#include "cv_utils.h"
#include "gs_globals.h"
#include "gs_options.h"

namespace golf_sim {

    class CameraHardware {

    public:

        // If set to >0, init_camera_parameters will use these values instead of camera-model-specific values
        // That way, if you want to use an image with X,Y resolution different than the current camera, you
        // can sort of make-believe that a camera with just your X,Y resolution took the picture.
        // TBD - Should not be static
        static int resolution_x_override_;
        static int resolution_y_override_;

        int CAMERA_NUM_PICTURES_TO_TAKE = 2;

        enum CameraModel {
            PiCam13 = 1,
            PiCam2 = 2,
            PiHQCam6mmWideLens = 3,
            PiGSCam6mmWideLens = 4,
            kUnknown = 100
        };

        // An initial set of states to simulate a camera repeatedly taking pictures until
        // (at some point in time), the object of interest in the image changes.
        // Was used to test the camera 1 movement processing.
        enum TestVideoState {
            ImagesLoaded,
            TakingInitialStaticFrames,
            FirstMovementFrame,
            BallGoneFrames
        };

        GsCameraNumber camera_number_ = GsCameraNumber::kGsCamera1;

        CameraModel cameraModel = CameraModel::PiHQCam6mmWideLens;
        float focal_length_ = 0;        // In millimeters
        float horizontalFoV = 0;        // In degrees
        float verticalFoV = 0;          // In degrees
        float sensor_width_ = 0;        // The physical size of the camera sensor, inclusive of all the pixels.  In mm
        float sensor_height_ = 0;       // In mm

        cv::Mat calibrationMatrix;
        cv::Mat cameraDistortionVector;

        // These SHOULD depend on camera model - TBD?
        // -1 if not set via init_camera_parameters or otherwise overridden
        int resolution_x_ = -1;
        int resolution_y_ = -1;

        cv::Vec2d camera_angles_;

        int expected_ball_radius_pixels_at_40cm_ = 0;

        // if set, the camera will use this image (file) as if (it were the image that the
        // camera took on the Pi, regardless of operating system.  First will be used first, then
        // if another picture is needed, the second will be used.
        std::string firstCannedImageFileName;
        std::string secondCannedImageFileName;

        cv::Mat firstCannedImage;
        cv::Mat secondCannedImage;

        // true; if the camera is all ready to go to take a picture.
        bool cameraReady = false;

        CameraHardware();
        ~CameraHardware();

        // Used when using test images instead of live photos
        // Pre-loads the test images to allow for faster simulated returns of them
        void load_test_images();

        void init_camera();
        void deinit_camera();

        void init_camera_parameters(const GsCameraNumber camera_number, const CameraModel model);

        bool prepareToTakePhoto();
        cv::Mat take_photo();

        bool prepareToTakeVideo();
        cv::Mat getNextFrame();

        // TBD - Probably should be private, but the higher-level golf_sim_camara needs to check this sometimes
        bool cameraInitialized = false;

    private:

        // Counts the number of static images that have been sent so far if this camera is
        // being emulated by software to take the place of a real camera.
        int staticImagesSent = 0;

        TestVideoState testVideoState = TestVideoState::ImagesLoaded;
        int currentStaticImageIndex = 0;
    };

}
